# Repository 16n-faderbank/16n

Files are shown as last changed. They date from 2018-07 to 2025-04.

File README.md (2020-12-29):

# 16n

Once upon a time, Sean Hellfritsch and Brian Crabtree [made a faderbank][linespost].

**16n** is the revised version of that object: it is open-source and ready for you to make, modify, or hack.

It is currently at hardware version **1.34**, firmware version **2.1.0**.

# Repository contents

- `firmware` is the Teensy source code.
- `electronics` is schematics and gerber files for the PCB.
- `panel` is SVG/DXF files for top and bottom panels.
- `build` is build documentation.
- `browser_test` is a **legacy** test webpage to let you test your 16n. As of 16n 2.0.0, the [editor][editor] should be your point of call for debugging your 16n.

Each directory has further `README` files in for you to read.

Your first point of call for documentation, however, should be the [Github Wiki][wiki].

## 16n Details

- 16 60mm faders
- sixteen CCs over USB-midi
- sixten CCs over minijack midi (with switch to swap between standards)
- sixteen 0-5V CV output jacks, one per channel.
- I2C: monome-style I2C protocol over TRS (tip is SDA, ring is SCL), works with Monome Teletype; also, I2C MASTER mode, works with monome Ansible, ER-301, TXo, etc (may require firmware patching or modification to connected device).

Power from 5V micro-usb into Teensy on left-hand side, or from your computer.

Toggle switch allows you to swap between 'Arturia/Novation' (tip is current source) and 'Korg/Makenoise' (ring is current source) standards; board is labelled such.

## Give us a picture, then

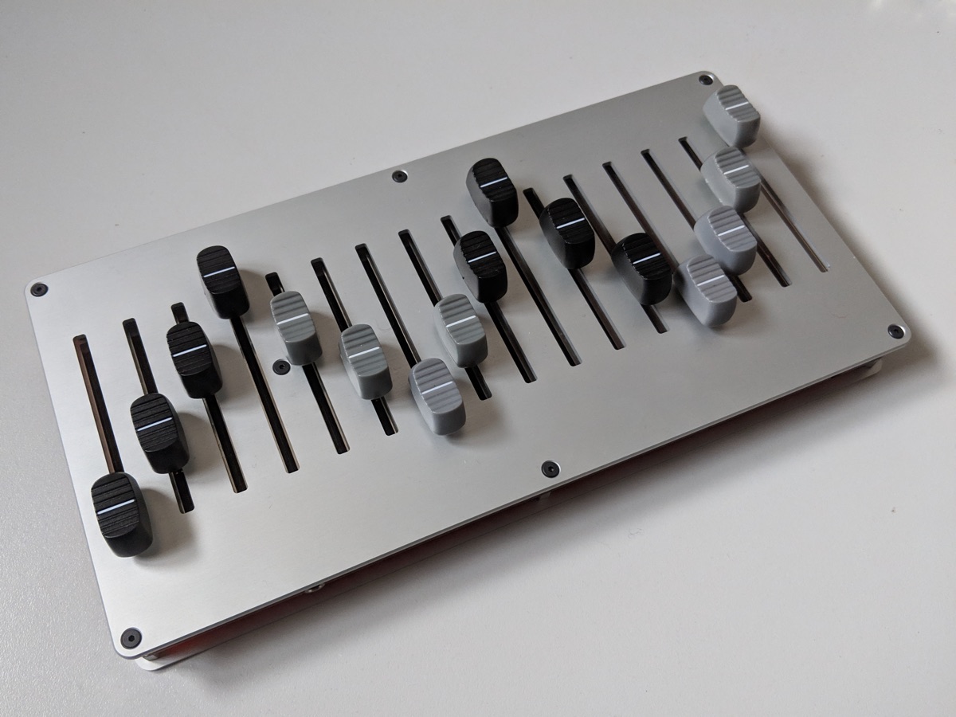
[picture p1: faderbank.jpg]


## User guide

[The user guide can be found on the Wiki](https://github.com/16n-faderbank/16n/wiki/User-Guide)

## BOM

[See more on the wiki](https://github.com/16n-faderbank/16n/wiki/BOM-(Bill-of-Materials))

## Build Guide

[See more on the wiki](https://github.com/16n-faderbank/16n/wiki/Build-guide)

## Credits

Based on original work by [Brian Crabtree][tehn] and Sean Hellfritsch.  
Minijack MIDI, I2C circuitry and CV outputs by [Tom Armitage][infovore].  
Firmware by [Brian Crabtree][tehn], [Tom Armitage][infovore], and [Brendon Cassidy][bpcmusic].

## Licensing

Panels and electronic schematics/layouts/gerber files are licensed under
[Creative Commons Attribution Share-Alike 4.0][ccbysa].

Firmware is licensed under the [MIT License][mitlicense].

[linespost]: https://llllllll.co/t/sixteen-n-faderbank/3643
[tehn]: https://github.com/tehn
[bpcmusic]: https://github.com/bpcmusic
[infovore]: https://github.com/infovore
[octobom]: https://octopart.com/bom-tool/unJxkzvR
[ccbysa]: https://creativecommons.org/licenses/by-sa/4.0/
[mitlicense]: https://opensource.org/licenses/MIT
[editor]: https://16n-faderbank.github.io/editor
[wiki]: https://github.com/16n-faderbank/16n/wiki

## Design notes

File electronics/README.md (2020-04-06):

# 16n electronics

Electronics CAD and design for the 16n faderbank. These currently use Autodesk EAGLE.

## VERSION

1.34

## Directory contents

* `16n.sch` and `16n.brd` are EAGLE 9.5.x format schematic and board layout for the project.
* `16n_schematic.pdf` is the schematic in PDF format.
* `16n_v126.brd/sch` are **old, legacy layouts that are not recommended for use**. They are kept for historical reasons.
* `bom.csv` is a CSV rendition of a BOM for the project. The parts are all highly generic - any brand of 0805 resistors will do, for instance. For more specific recommendations, the [live BOM at Octopart][octobom] has links to specific components, designed around things easily purchased from Mouser, though note that stock of one manufacturer's parts may not be guaranteed, and you might need to edit your basket to find parts in stock.
* `gerbers` contains RS-274x format Gerber files for the current version of the board. These files are named per OSHpark standards, though OSHpark is an expensive place to make a 16n - you may wish to rename before you send them to another manufacturer. Do not assume your fab house can just make these - if your fab house has specific CAM rules, you should generate your own Gerbers from EAGLE.

---

[octobom]: https://octopart.com/bom-tool/unJxkzvR

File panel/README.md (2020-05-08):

# 16n: panels

- `16n-134-top.dxf` and `16n-134-bottom.dxf` are the two panels, as exported from the CAD tools they were designed in. These should be the files you make your panel from if at all possible.
- `16n-134-top.fpd` and `16n-134-bottom.fpd` are the two panels in the correct format for Schroff's _Front Panel Designer_ software. M2.5 hardware, with countersinks.
- `16n-134-top.pdf` and `16n-134-bottom.pdf` are the two panels at life-size in PDF format, with a very, very fine stroke - suitable for laser-cutting. Be sure to check the dimensions of the files in your laser-cutting platform before you start cutting.
- `16n-134-bottom-drawing.pdf` and `16n-134-top-drawing.pdf` **are mechanical drawings** of the upper and lower panels. Note that they are drawn with countersinks for a metal panel, but do not necessarily require them. All mounting holes are M2.5, all countersinks are 5.5mm. As mechanical drawings, you should **not** use these as files to send to CNC; they are purely for visual reference.

If you need to check dimensions when you import these files into your graphics program of choice, the mechanical drawing is good reference: the panel should be 254mm across its longest dimension, edge to edge.

FPD files by [Raph Wlodarczyk](https://github.com/altitude909).

PDF files for lasercutting by Matt Kennedy.

## License

This work is licensed under the Creative Commons Attribution-ShareAlike 4.0 International License. To view a copy of this license, visit http://creativecommons.org/licenses/by-sa/4.0/ or send a letter to Creative Commons, PO Box 1866, Mountain View, CA 94042, USA.

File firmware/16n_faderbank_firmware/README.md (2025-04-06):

# 16n Firmware

16n Firmware is designed to run on a Teensy 3.2; it is also compatible with a Teensy LC, although the official BOM recommends a 3.2.

This README serves as a guide for **developing** and **compiling** your own versions of the firwmare. Since firmware v2.0.0, the recommended method for putting firmware onto a 16n is to use Teensy Loader directly. [Find out more on the wiki][load-firmware]

If you are interested in compiling your own firmware, or hacking on it, read on!

## Requirements

- Arduino + Teensyduino install (currently: [Arduino](https://www.arduino.cc/en/software) 2.3.4 with [Teensyduino](https://www.pjrc.com/teensy/td_download.html) v1.59.0)
- `ResponsiveAnalogRead` library
- `CD74HC4067` library

## Compilation

- You **must** compile this with Tools->USB type set to **MIDI**. (**Serial+MIDI** may have issues with certain devices you connect to).
- Be sure that the board speed is set to 120mhz (overclock) for maximum repsonsiveness.
- If you're having issues compiling related to MIDI libraries or code: make sure your Arduino `libraries` folder doesn't have any old versions of weird MIDI libraries in. The MIDI library should be installed by default via Teensyduino; otherwise, if you have the latest version of the 47effects MIDI library in your Libraries Manager, that'll also behave. It turns out that older versions in the legacy `libraries` folder sometimes lead to conflicts.

## Customisation and configuration

As of 16n firmware 2.0.0, you no longer should do ANY configuration through the Arduino IDE. All configuration is conducted from a web browser, using the [16n editor][editor]

When you upgrade to 2.0.0 you will LOSE ANY CONFIGURATION YOU HAVE from v1.3x. This is a one-time thing; apologies. You will not lose future configurations (and also, they are easier to back up).

The 16n will be initialised to a set of default settings (All outputs for TRS and USB set to MIDI channel 1, CCs 32-47, I2C set to follower). Once this is done, connect over USB, and go to the [editor][editor] in Google Chrome; you will be able to see the current configuration, edit the configuration, and transmit the new config to your device. You will likely need to customise the maximum fader value calibrations.

Note that if you do change any config related to I2C, you should power-cycle the 16n before it will be picked up.

Some options _do_ remain in `config.h`; they are for developers to specify options that are likely to need setting once, or adjusting during the development process:

In `config.h`

```C
#define DEBUG 1
```

will log debug messages to the serial port.

```C
#define DEV 1
```

will restrict the faderbank to its first channel. Designed for breadboard development; almost certainly not of interest.

## Memory Map

Configuration is stored in the first 86 bytes of the on-board EEPROM. It looks like this:

Addresses 0-15 are reserved for configuration flags/data.

FADERMAX and FADERMIN are 14-bit numbers; as such, they are stored in two bytes as MSB and LSB; the actual number is calculated by `(MSB << 8) + LSB`

| Address | Format  | Description |
|---|---|---|
| 0 | 0/1 | LED on when powered |
| 1 | 0/1 | LED blink on MIDI data |
| 2 | 0/1 | Rotate controller outputs via 180º |
| 3 | 0/1 | I2C Master/Follower |
| 4,5 | 0-127 | FADERMIN lsb/msb |
| 6,7 | 0-127 | FADERMAX lsb/msb |
| 8 | 0/1 | Soft MIDI thru (default 0) |
| 9-15 | | Currently unused |
| 16-31 | 0-15 | Channel for each control (USB) |
| 32-47 | 0-15 | Channel for each control (TRS) |
| 48-63 | 0-127 | CC for each control (USB) |
| 64-79 | 0-127 | CC for each control (TRS) |
| 80-82 | 0-127 | Booleans for high-res mode (USB) |
| 83-85 | 0-127 | Booleans for high-res mode (TRS) |

## LICENSING

see `LICENSE`

[load-firmware]: https://github.com/16n-faderbank/16n/wiki/Firmware:-installation-instructions
[editor]: https://16n-faderbank.github.io/editor

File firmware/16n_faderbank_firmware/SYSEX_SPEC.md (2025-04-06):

# 16n Sysex spec

The 16n interfaces with its editor via MIDI Sysex. This document describes the supported messages.

## `0x1F` - "1nFo"

Request for 16n to transmit current state via sysex. No other payload.

## `0x0F` - "c0nFig"

"Here is my current config." Only sent by 16n as an outbound message, in response to `0x1F`. Payload of 80 bytes, describing current EEPROM state.

## `0x0E` - "c0nfig Edit"

"Here is a new complete configuration for you". Payload (other than mfg header, top/tail, etc) of 80 bytes to go straight into EEPROM, according to the memory map described in `README.md`.

## `0x0D` - "c0nfig edit (Device options)"

"Here is a new set of device options for you". Payload (other than mfg header, top/tail, etc) of 16 bytes to go straight into appropriate locations of EEPROM, according to the memory map described in `README.md`.

## `0x0C` - "c0nfig edit (usb options)"

"Here is a new set of USB options for you". Payload (other than mfg header, top/tail, etc) of 34 bytes to go straight into appropriate locations of EEPROM, according to the memory map described in `README.md`.

## `0x0B` - "c0nfig edit (trs options)"

"Here is a new set of TRS options for you". Payload (other than mfg header, top/tail, etc) of 34 bytes to go straight into appropriate locations of EEPROM, according to the memory map described in `README.md`.

## `0x1A` - "1nitiAlize memory"

"Wipe the EEPROM and force factory settings". Unlikely to ever be needed. The use case is "emptying" the EEPROM of a Teensy that's previously been used for other projects, and thus has an inaccurate configuration on it.

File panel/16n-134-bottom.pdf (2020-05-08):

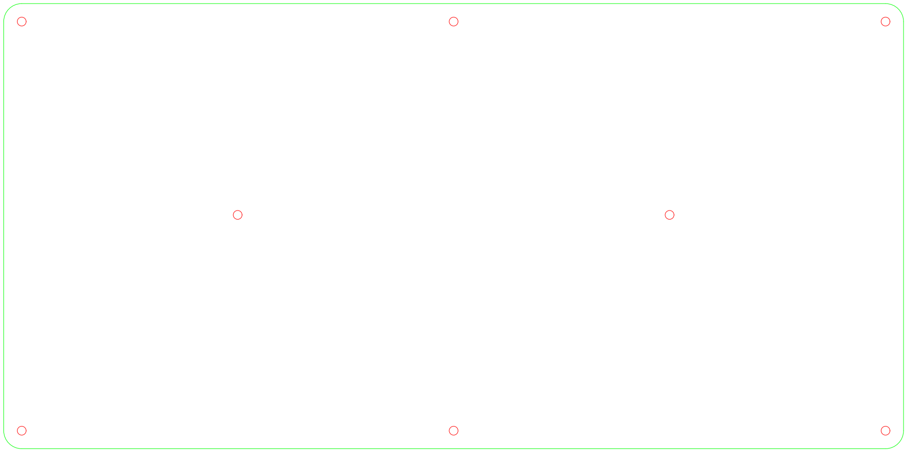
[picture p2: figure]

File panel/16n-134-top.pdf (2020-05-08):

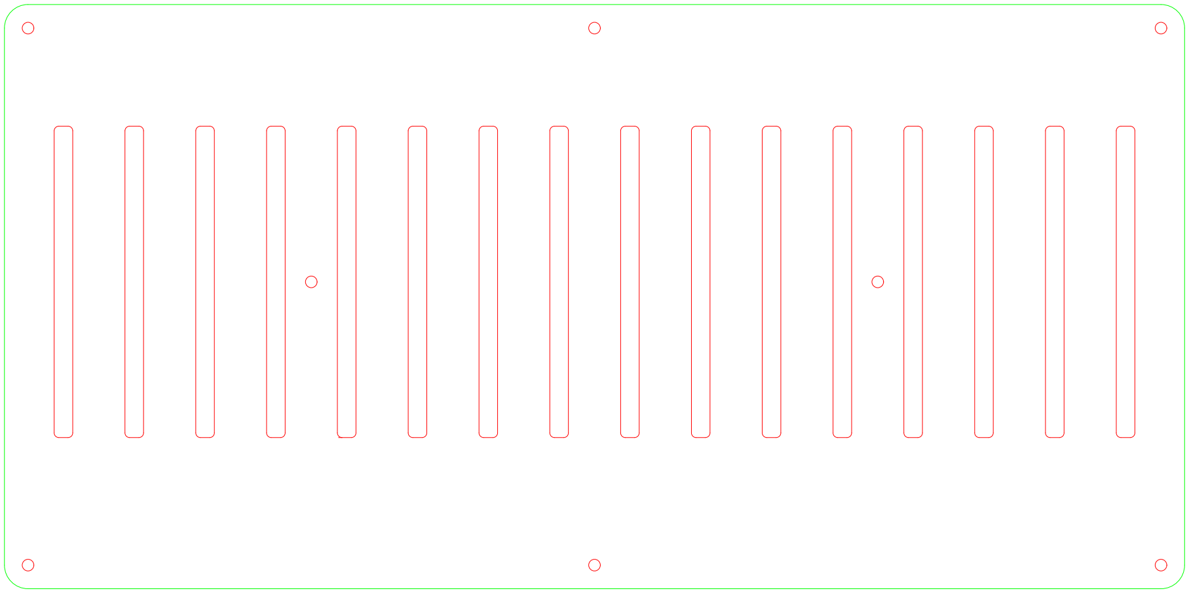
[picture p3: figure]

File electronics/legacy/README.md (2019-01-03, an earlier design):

# Legacy electronics

This directory contains older versions of the 16n circuit and PCB that are no
longer recommended for use; they are simply kept around for legacy reasons as
a few of these exist in the world. `16n.sch` and `16n.brd` in the parent
directory are the versions you should refer to.

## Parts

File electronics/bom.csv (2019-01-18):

Qty | Value | Device | Package | Parts | Description
2 |  | AUDIO-JACKPTH | AUDIO-JACK | JP1, JP2 | 3.5mm Stereo Audio Jack CUI SJ1-3523N
4 |  | DIODESOD123 | SOD-123 | D1, D2, D3, D4 | 1N4148 SOD-123 didoe
1 |  | SWITCH-DPDTEG2211 | EG2211 | S1 | DPDT Version of the COM-00597
9 | 100n | C-EUC0805 | C0805 | C1, C2, C3, C4, C5, C6, C7, C8, C9 | 0805 X7R capacitors
16 | 10K | R-EU_R0805 | R0805 | R20, R22, R24, R26, R28, R30, R32, R34, R36, R38, R40, R42, R44, R46, R48, R51 | 0805 1% Resistors
16 | 1K | R-EU_R0805 | R0805 | R1, R2, R3, R4, R5, R6, R7, R8, R9, R10, R11, R12, R13, R14, R15, R16 | 0805 1% Resistors
2 | 47 | R-EU_R0805 | R0805 | R49, R52 | 0805 1% Resistors
16 | 5.6K | R-EU_R0805 | R0805 | R19, R21, R23, R25, R27, R29, R31, R33, R35, R37, R39, R41, R43, R45, R47, R50 | 0805 1% Resistors
1 | CD74HC4067M | 744067SO24 | SOIC127P1030X265-24 | U1 | 16-channel analog MUX
2 | DNP | R-EU_R0805 | R0805 | R17, R18 | 0805 1% Resistors
8 | MCP6004_SMD | MCP6004_SMD | SO14 | U2, U3, U4, U5, U6, U7, U8, U9 | MCP6004 quad op amp
16 | PJ302M | PJ302M | PJ302M | J1, J2, J3, J4, J5, J6, J7, J8, J9, J10, J11, J12, J13, J14, J15, J16 | PJ302M horizontal / right angled mount 3.5 mm jack socket (available at Thonk) or CUI MJ-3536 (more expensive)
16 | SLIDEPOT-ALPS-60MM | SLIDEPOT-ALPS-60MM | RS6011SP6003 | U$1, U$2, U$3, U$4, U$5, U$6, U$7, U$8, U$9, U$10, U$11, U$12, U$13, U$14, U$15, U$16
1 | TEENSY_3.1-3.2_DIL | TEENSY_3.1-3.2_DIL | TEENSY_3.0-3.2&LC_DIL | U$17 | Teensy 3.1 or 3.2 in a DIL Layout.
Hardware
8 | Harwin R25-1001002 |  |  |  | 10mm F-F standoff
8 | Harwin R25-3000602 |  |  |  | 6mm M-F standoff

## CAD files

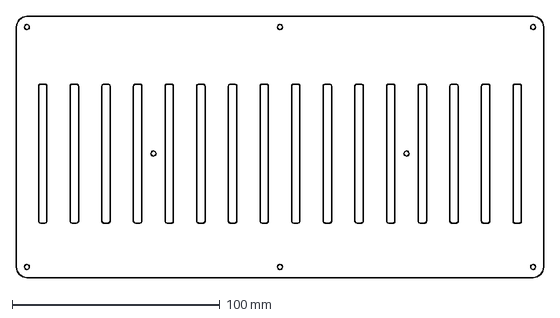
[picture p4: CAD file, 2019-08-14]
panel/16n-134-top.dxf
254.0 x 125.7 mm

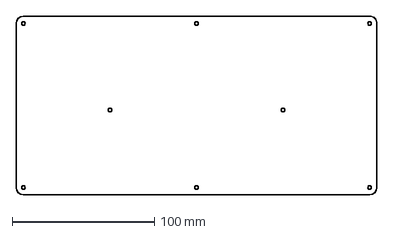
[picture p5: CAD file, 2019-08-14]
panel/16n-134-bottom.dxf
254.0 x 125.7 mm

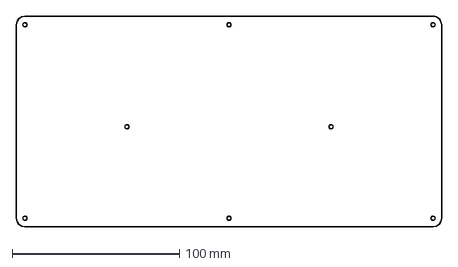
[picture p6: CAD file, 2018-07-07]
panel/16n-125-bottom.dxf
254.0 x 125.7 mm

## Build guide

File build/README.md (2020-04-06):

# 16n: v1.3x build guide

[The build guide now lives on the wiki](https://github.com/16n-faderbank/16n/wiki/Build-guide)

This directory stores the images for the build guide; do not remove.

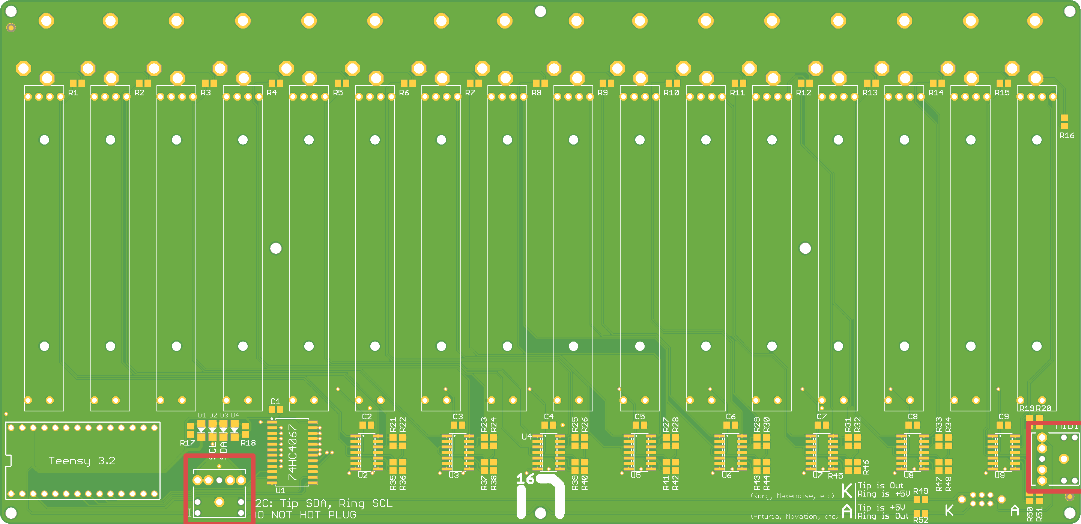
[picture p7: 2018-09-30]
build/build/16n_5_stereo.png

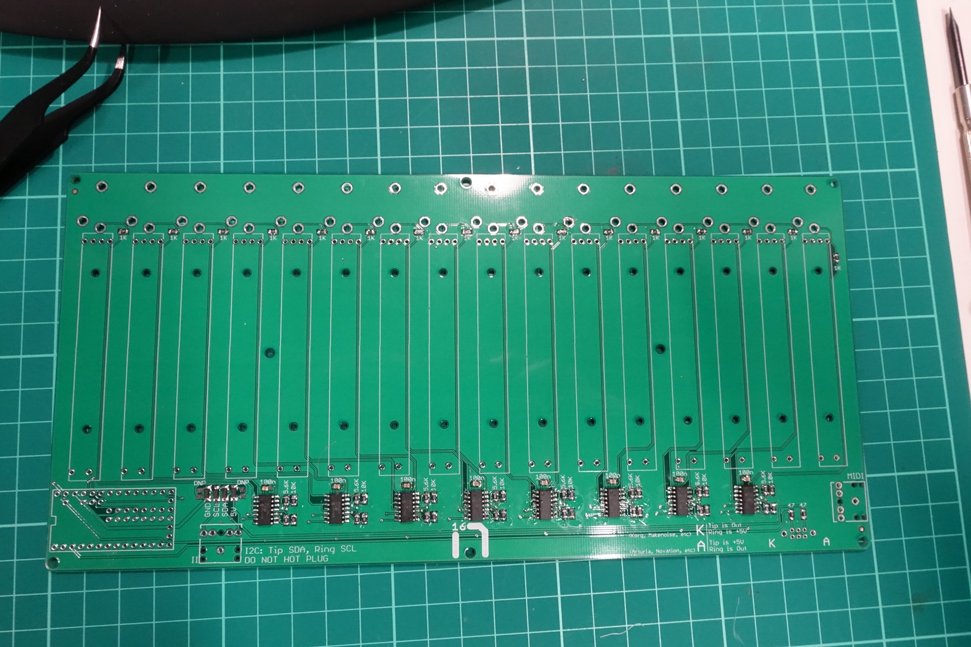
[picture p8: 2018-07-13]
build/build/DSC01717.JPG

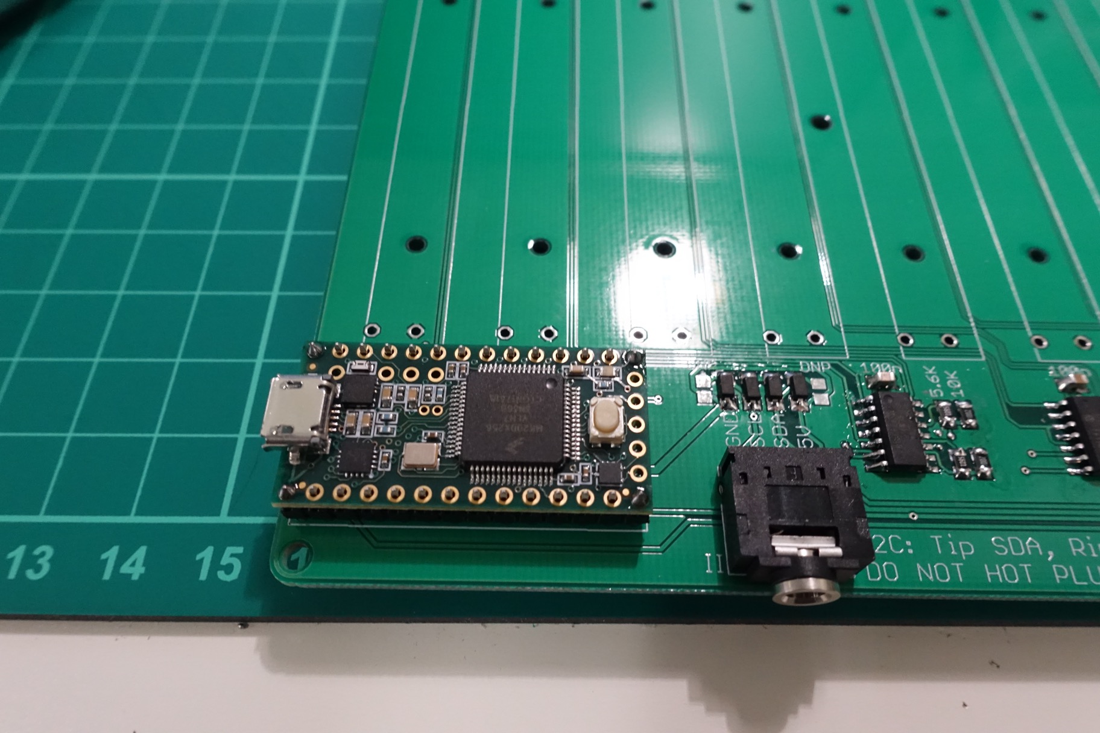
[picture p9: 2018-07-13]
build/build/DSC01723.JPG

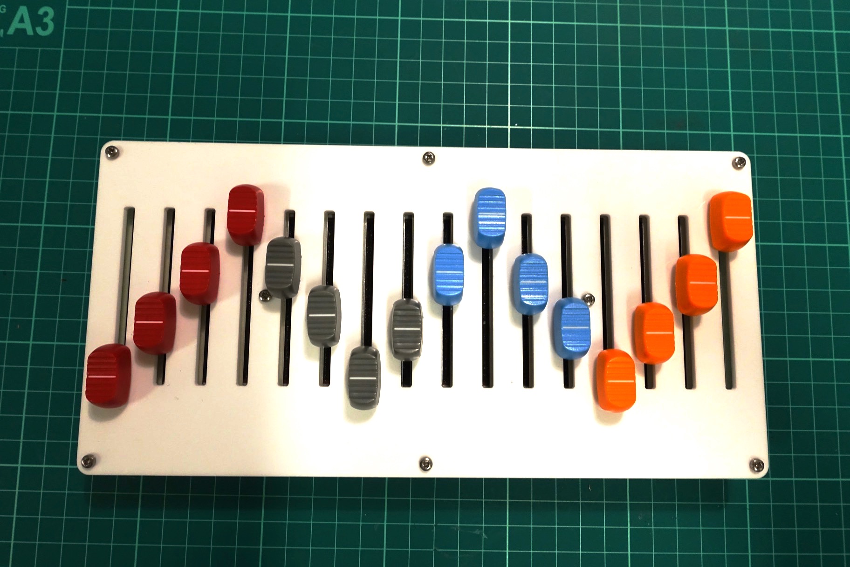
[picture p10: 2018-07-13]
build/build/16n_2.jpg

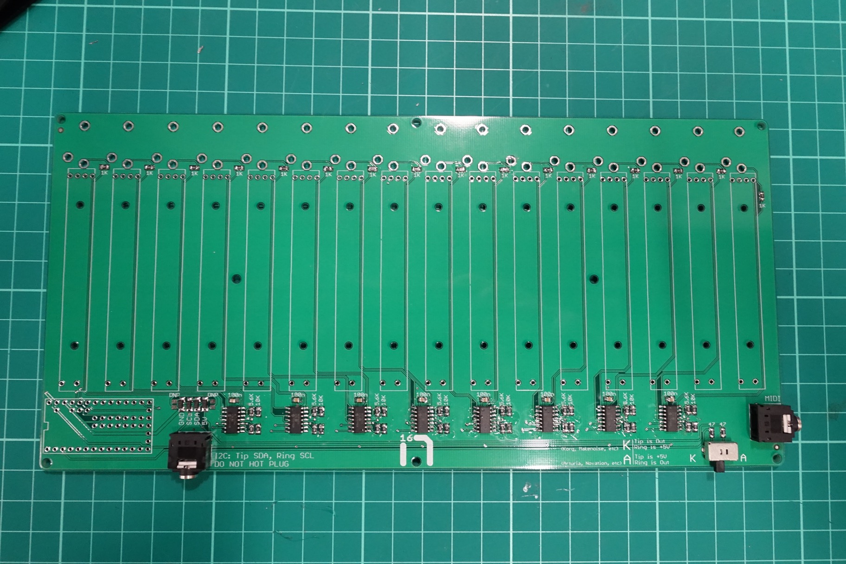
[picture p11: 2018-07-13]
build/build/DSC01721.JPG

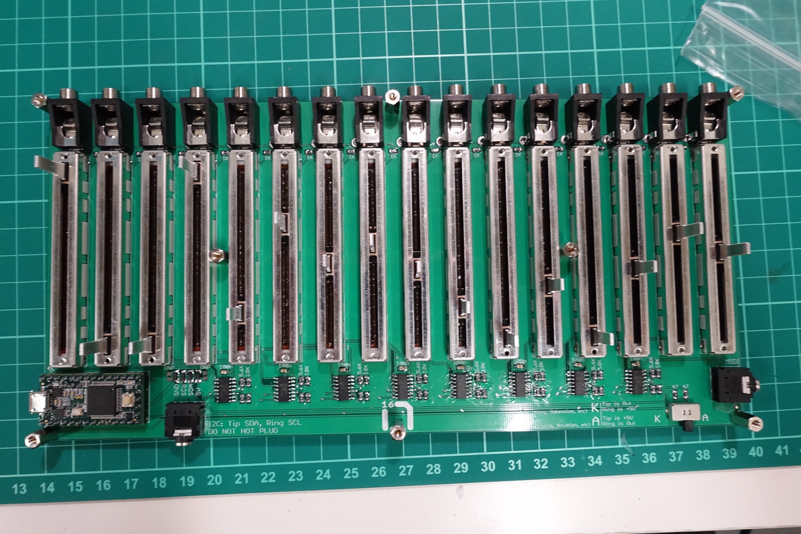
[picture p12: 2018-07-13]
build/build/DSC01729.JPG

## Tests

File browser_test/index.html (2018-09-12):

# 16n MIDI test

This test page requires a WebMIDI compatible browser; we recommend Google Chrome.

Connect your 16n via USB _or_ hardware MIDI, not both. You should see sixteen sliders that move independently when your 16n is connected. This assumes the default midi settings of CCs 32-47.

1

1

1

1

1

1

1

1

1

1

1

1

1

1

1

1

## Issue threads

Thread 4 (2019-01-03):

Add version number to Eagle files?

okyeron, 2019-01-03:
At first glance it's not obvious which eagle files are the ones to use.

Adding a version number or putting the old (1.26) version in a separate folder would help reduce confusion.

infovore, 2019-01-03:
v1.26 has been removed from the repository, because we have git history now, and no-one really should be using 1.2x.

My goal is to only have one current version. Version number is written on the rear silk of the BoaRD file - it should probably be in the SCHematic, too, though. Thoughts?

infovore, 2019-01-03:
I thought about removing v1.26  from the repository, because we have git history now, and no-one really should be using 1.2x. However, I might bung it in a folder called `legacy` and leave it at that.

My goal is to only have one current version. Version number is written on the rear silk of the BoaRD file - it should probably be in the SCHematic, too, though. Thoughts?

infovore, 2019-01-03:
(See
https://github.com/16n-faderbank/16n/tree/master/electronics/legacy)

okyeron, 2019-01-03:
Adding version to the schematic would be great.

Closed 2019-01-15.

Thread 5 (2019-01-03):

Slide Pots - 10K?

okyeron, 2019-01-03:
BOM is not specific on value for slide pots.

Mouser lists 2 versions of the RS6011SP600x - RS6011SP6003 (10KOhms) and RS6011SP6004 (20Kohms)

Datasheet says the 10K RS6011SP6003 is 1B taper (linear) so I assume this is the right one. Might be good to update the BOM with that part number?

infovore, 2019-01-03:
Octopart BOM - https://octopart.com/bom-tool/unJxkzvR - is specific and specifies 6003 (10k) parts.

However, technically, resistance doesn't matter that much as it's just being used as a voltage divider. Taper is, however, critical, and should be linear. I'll update `bom.csv` with the 6003 part though.

Closed 2019-01-03.

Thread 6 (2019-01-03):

Multiplexer missing from CSV BOM and Octopart BOM

infovore, 2019-01-03:
...and if it is, does that mean cap counts are correct too? Double check.

infovore, 2019-01-03:
Nope - turns out the _wrong_ Octopart BOM was linked up. Fixed, now.

Elberstein, 2019-01-18:
BOM.csv should be modified, it still lists CD74HC4067SM96 as multiplexer but it's the wrong package. It should be CD74HC4067M

Closed 2019-01-18.

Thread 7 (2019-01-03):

Standoff height?

okyeron, 2019-01-03:
Another discrepancy between Octopart BOM and CSV...

The CSV has 6mm M-F standoff, Octopart has 5mm

Should we assume Octopart BOM is correct?

infovore, 2019-01-03:
Well.

6mm is correct, but even though Harwin make a 6mm M-F spacer, Octopart doesn't list it.

Also: this is dependent on the length of your screws. With the counterrsunk screws, I needed a 6mm spacer to accommodate them; with panheads, the 5mm one was fine. I could go looking for alternate parts. If you're not using countersunk holes, 5mm should be fine.

This is a weird discrepancy, but I'm not sure how best to solve it.

okyeron, 2019-01-03:
So here's alternate part from mouser that's 6mm, but only 4.5 wide
https://www.mouser.com/ProductDetail/RAF-Electronic-Hardware/M2101-2545-AL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

Might be good to mention the length being an option in the docs?

okyeron, 2019-01-28:
Followup thought -  if your fader bats/arms/shafts (what are those called anyway) are too long/tall for your chosen fader caps, you could potentially get longer top spacers to raise the panel up a bit.

Useful addendum  for the build docs?

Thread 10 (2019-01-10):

Bug in panel DXFs

infovore, 2019-01-10:
Panel DXFs have 5.5mm holes at the corners, not 2.5mm.

The 5.5mm is the countersink; the drill should be 2.5mm.

This can be attributed to the DXF being extracted from fusion360 from the wrong side. Needs fixing ASAP.

infovore, 2019-01-10:
(thanks, @okyeron)

Closed 2019-01-18.

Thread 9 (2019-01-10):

Issue compiling on Windows

infovore, 2019-01-10:
As seen here:
https://llllllll.co/t/16n-is-a-bank-of-faders-release-thread-current-version-1-31/18620/118

> I’m having problems compiling the code. 1.8.8/1.45 on win10 64bit.
> `_16n_faderbank_firmware:27: error: expected constructor, destructor, or type conversion before ‘;’ token MIDI_CREATE_DEFAULT_INSTANCE();`

altitude909, 2019-01-10:
following.

infovore, 2019-01-10:
@altitude909 so here's a question - in Sketch -> Libraries -> Manage Libraries  - can you find "MIDI Library by Forty-Seven Effects" and tell me what version you have installed? You shouldn't need this - Teensyduino includes a midi library - but I'm wondering if there's a version conflict. (I have 4.3.1 of this library installed, and all compiles fine).

altitude909, 2019-01-10:
yeah, wouldn't surprise me I think im up to 7 midi libraries in there. its still up on screen, I'll check in a bit

okyeron, 2019-01-10:
I think the 47-effects lib is deprecated now (after 1.8.5). The newest teensyduino should override this.

You could try disabling the 47-effects lib and/or reinstall teensyduino

infovore, 2019-01-10:
@okyeron in thread, @altitude909 said they were on Arduino 1.8.8, Teensyduino 1.45 (ie, all latest)

okyeron, 2019-01-10:
Right - scanner_darkly had the exact same error last night on some other teensy/midi code and he fixed it by upgrading to 1.8.8 and 1.45 (on windows).

In this case my guess is the 47effects midi lib is getting loaded instead of the Teensy one?

infovore, 2019-01-10:
@okyeron no; I have the 47effects library installed; everything compiles fine. However - I was wondering if there was a conflict with _older_ versions of 47effects, which had similar issues to the one described.

altitude909, 2019-01-10:
Ok, Used: p:\Program Files (x86)\Arduino\hardware\teensy\avr\libraries\MIDI is what worked.  I had a who knows what lib that is was trying and that was breaking the build

infovore, 2019-01-10:
@altitude909 ah, yeah - so there were some changes to the core MIDI libraries a while back; older versions seemed to trigger the error you described. Old things kicking around in `.../libraries` might do that.

I'm glad you've got it working. Outputs from this: I'm going to add this clarification in the `README` before closing this issue.

Closed 2019-01-18.

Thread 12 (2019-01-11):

I2C, slave mode: wrong address

Elberstein, 2019-01-11:
I'm experiencing issues with the I2C connection. I'm testing the connection with a Teletype, when polled, it always returns 0. (See "Context" below). According to the Serial Monitor, the 16n doesn’t receive anything.

I'm not sure wether it's related to hardware or software. If it's related to the hardware, the only change I made is replacing the 1N4148W-7-F diodes by 1N4148W**Q**-7-F diodes. The specs are nearly identical but the Q-7-F have a reverse current of 50uF instead of 1uF for the 7-F.
Could this be the cause of the issue ?

**Context:**
- Teletype (old hardware, not the latest revision) Firmware number -> 25E14EE
- TT busboard.
- 16nFaderbank in slave mode
- 16n connected to the I2C bus through a TXo.
- Total cable length outside + inside the eurorack case: approx. 35cm
- Connectivity between the Teletype and the Teensy tested with a multimeter: OK (Tip: SDA, Ring: SCL, Sleeve: ground. Pins 18 and 19 on the Teensy)
- The firmware of the 16n has not been modified (except for enabling DEBUG in config.h)
- Midi (USB) and CV tested: OK.
Other I2C devices on the bus:
Backpack header 1: ER-301
Backpack header 2: Two TXo + one 16n connected in series.

(Also tested with the 16n directly connected to the TT busboard)

**Situation:**
- The ER-301 and the TXOs receive messages from the Teletype.
- **The 16n in DEBUG mode doesn't receive messages from the Teletype according to the Serial Monitor.**
- **When polled from the Teletype with `FB 1`, the result is always 0, same thing for each fader.**
- Midi (USB) and CV work fine. Midi over jack not tested. Master mode not tested as it would require placing the pull-up resistors etc, but I can do it if necessary

Thanks.

Elberstein, 2019-01-12:
New test: Faderbank directly connected to the Teletype via i2C, removed all the other devices on the bus.
Result: Apparently the 16n stopped working (judging by the USB test in browser and the LED not lit on the Teensy I had to re-upload the firmware.

Elberstein, 2019-01-13:
Thanks for your reply.

I've just made a new test connecting the 16nFaderbank directly to the Teletype without busboard this time. As I wrote yesterday, the 16n didn't like being the only device on the I2C bus with the pull-up resistors of the TT busboard. This time, the unit doesn't stop working but it always returns 0.
I have to say that all the tests have been done with two 16nFaderbank successively, I built two.

Elberstein, 2019-01-14:
In Master mode this time, the serial monitor is full of i2c messages, the 16n is connected to the ER-301
but it doesn't receive anything. I think that's normal since the faderbank seems to send i2C to an address that is not longer used by the ER-301.

```
      // ER-301
      sendi2c(0xB0, 0, 0x11, q, notShiftyTemp);
```

The new address is 0x31 I'm opening a new issue for that.

      // ER-301
      sendi2c(0x31, 0, 0x11, q, notShiftyTemp);

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

Elberstein, 2019-01-14:
OK, the issue is now fixed @infovore and @bpcmusic , it's also an issue related to the I2C address.

The address should be **0x34 and not 0x80** according to https://github.com/monome/libavr32/blob/master/src/ii.h

```
  #else
  Wire.begin(I2C_SLAVE, 0x34, I2C_PINS_18_19, I2C_PULLUP_EXT, 400000);
  Wire.onReceive(i2cWrite);
  Wire.onRequest(i2cReadRequest);
```

bpcmusic, 2019-01-15:
Looks like there was some drift since the initial versions on both sides (TT and ER-301). I've been so neck-deep in my build that I haven't kept up. Thanks for catching it!

Elberstein, 2019-01-15:
Yes, for me the changes you've made are OK @infovore

infovore, 2019-01-18:
`master` branch is now up-to-date with correct addresses.

Closed 2019-01-18.

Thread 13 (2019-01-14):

I2C, wrong address for ER-301

Elberstein, 2019-01-14:
The i2C address 0xB0 is no longer used by the ER-301.

```
      // ER-301
      sendi2c(0xB0, 0, 0x11, q, notShiftyTemp);
```

The new address should be 0x31 or 0x32 or 0x33

```
  // ER-301
  sendi2c(0x31, 0, 0x11, q, notShiftyTemp);
```

infovore, 2019-01-18:
`master` branch is now up-to-date with correct addresses.

Closed 2019-01-18.

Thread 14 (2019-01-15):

Flip device

Elberstein, 2019-01-15:
It would useful to have the possibility to flip the device, I2C connector on top, midi connector on the left.

In config.h there's an option for the fader numbers `#define REV 1` but what is the best way to also invert the values ?

I replaced   `temp = map(temp, MINFADER, MAXFADER, 0, 16383);`
with   ` temp = map(temp, MINFADER, MAXFADER, 16383, 0);`

It works but the lowest MIDI value is always 2 or 3. How can I adjust that please ?

infovore, 2019-01-15:
I'll have a think. I think the nice feature would be to have a single `define` flag like the L-R reversing, called `FLIP`, that would just make this happen.

infovore, 2019-01-15:
In the meantime - have a go at reducing `MINFADER`, which is line 34 in `config.h` - basically, might be worth fettling the sensitivity of the analog read. I'll look into this further in coming days. For now, I'm just kicking off a branch to work on this.

Elberstein, 2019-01-15:
Unfortunately, the hack `temp = map(temp, MINFADER, MAXFADER, 16383, 0);` doesn't seem to work with I2C, and reducing the value of MINFADER does't seem to have any effect

infovore, 2019-01-15:
OK, duly noted. Pretty sure I can come up with a solution for this - but not before Friday this week!

infovore, 2019-01-18:
OK, @Elberstein . I've taken a quick pass at this in a branch and got a PR open for it - https://github.com/16n-faderbank/16n/pull/17 . If you're comfortable downloading that branch and flashing that firmware, can you let me know how you get on? I've tested it on my 16n, which, over USB MIDI, behaves correctly when `REV` and `FLIP` config settings are set to 1. We can move discussion over to the PR if you'd like.

Elberstein, 2019-01-18:
I'm not really familiar with Github, I have to learn but it's not a problem.
Thanks for adding this feature. I've just tested it with the Teletype. It works but the minimum value is around 350 even if MINFADER is set to 0

infovore, 2019-01-18:
OK, I think I have it working now. If you get the firmware in this branch - https://github.com/16n-faderbank/16n/tree/flip_feature - and enable `FLIP` and `REV`, my debug log seems to send correct I2C out when the thing is upside down.

Elberstein, 2019-01-18:
Yes it works but I have to increase the MINFADER value up to 200

infovore, 2019-01-20:
Merged to master.

Closed 2019-01-20.

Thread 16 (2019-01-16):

Multiple faderbanks on the same I2C bus

Elberstein, 2019-01-16:
Is it technically possible to have multiple faderbanks on the same I2C bus ? I'm wondering if it has already been tested.

Out of curiosity I tried to add an offset here but of course, it doesn't work :-) And I realize that teletype/src/ops/fader.c would probably need a modification, too.

```
    // map and update the value
    noInterrupts();
    currentValue[i] = temp;
    interrupts();
```

Thanks.

infovore, 2019-01-18:
I don't think so. Disclaimer: I am not the I2C expert.

Basically, in non-master mode - the default for Teletype - each device needs an address, and Teletype only knows one 16n address (for the device `fader`); adding more faderbanks would need more addresses over in Teletype land.

It _might_ be more possible in MASTER mode, because it's multiple devices sending to endpoints, but even then, code modification would be required - setting custom addresses, possibly changing the fader data sent over I2C.

So: for now, I'm paging Brendon (when he has time), but my gut says not without significant work. I also think that work would be largely user-unfriendly for an edge case.

Elberstein, 2019-01-18:
Thanks for your reply.
Yes, I see two options for the Slave mode:

A: Probably the best solution. More addresses in Teletype like you're suggesting (i.e: 0x35 etc.) and the user can change this line to reflect the address of the device   `Wire.begin(I2C_MASTER, **0x35**, I2C_PINS_18_19, I2C_PULLUP_EXT, 400000); ` or a variable in config.h (?)

B: Increasing the number of ports in Teletype (fader) and adding an offset (+ 16, +32) to the port number, that seems more complicated.

In both cases, it requires a modification of the teletype code.

Multiple Masters on the same bus: I'm not sure what will happen but I need to try that, if one faderbank can talk to the Teletype and another to the ER-301 while keeping the ER-301 connected to Teletype, that would be great.

bpcmusic, 2019-01-19:
You could have a one in normal mode and one in master mode, i think (but haven't tried it). Things get complicated with the Teletype as it isn't a fan of multiple masters at the moment. So, until that gets resolved (and scanner_darkly has a lead on that), you wouldn't have a stable multi-master configuration.

If you want to have two that you READ from, we could enhance the firmware to support another set of addresses. It would work the same way that it was coded for the TXi. Basically, the Teletype knows that each device has N inputs and for queries outside of that index, it advances in the address space one and normalizes to the appropriate input on the device. For example, TI.PRM 5 = TI address #2; knob 1.

That all means adding more sequential addresses for the 16n and updating the TT code to know about multiple 16n. At the bare minimum, the 16n firmware would need to be updated and compiled with the new address(es). It also could be modified to increment the ports that it sends to in Master mode - which would make sense.

I decided not to do all this (even though I have the code from my TXi implementation) to keep things simple and easy to modify by others. Given the Teletype's script limitations, I've found creatively using all 16 sliders to be a challenge in and of itself. :)

infovore, 2019-01-20:
@Elberstein I think this is effectively resolved? Before I close it, I think the best thing to do is convert @bpcmusic's response into some documentation. Is that OK?

Elberstein, 2019-01-20:
Yes, the work is on the Teletype side, I think we can close this issue :-)

Closed 2019-01-20.

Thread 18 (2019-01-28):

Put i2c address in config.h

okyeron, 2019-01-28:
Just in case people want to change the i2c address, it would be way easier to have that as a DEFINE in config.h instead of hardcoded in `Wire.begin()`

infovore, 2019-01-28:
Good idea. PR/branch open here for your review: https://github.com/16n-faderbank/16n/pull/20

infovore, 2019-02-01:
Fixed!

Closed 2019-02-01.

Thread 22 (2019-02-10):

Has anyone replaced ALP sliders with Bournes LED sliders?

JKMinWA, 2019-02-10:
I'd like to build this, but can't find the ALPS faders listed in the BOM.  I'd prefer to have faders with LEDs and found Bournes faders with dimensions and mechanical and electrical characteristics comparable to the ALPS that have LEDs in the lever.  Has anyone made this substitution?  Is this a straightforward replacement, or is there some other factors I need to consider or adjustments I need to make?

Thanks in advance for any advice.

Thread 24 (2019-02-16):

Panel thickness?

cschol, 2019-02-16:
Using the Alps faders from the BOM, what is the optimal panel **thickness**, especially for the top panel?

okyeron, 2019-02-20:
Depends on your fader caps maybe?

The mixer style caps I have are meant to be more flush to the panel so I found using a 13mm spacer with a 1/8in panel works well.

infovore, 2019-02-20:
In the images you've seen of the aluminium panel, I've been using 2mm aluminium. I've also successfully made one with 3mm plastic. The plastic one uses 10mm spacers up top, 5mm below; the metal one uses 6mm spacers below owing to countersunk holes requiring a bit more depth for the screws. Does that help?

cschol, 2019-02-20:
Yes. Thanks! I have ordered a 3mm plastic panels. That should work.

Closed 2019-02-21.

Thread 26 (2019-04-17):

faders not going to full value on midi

altitude909, 2019-04-17:
Someone brought up that their device is sending CC values over 124 and I checked several devices here and some do some do some dont.  Its persistent over all the faders for given device.  5V is good in all cases..

jamiemccusker, 2019-05-06:
Same issue here in the one I’ve built . Midi goes from 0-124. Any ideas?

andrewh, 2019-05-06:
I've also had issues finding the right values for `MINFADER` and `MAXFADER` in `config.h`. Would be good to know what others are using to get stable 0-127 over usb-midi.

I've played around and had `MINFADER` at 294 which went to MIDI 0, and `MAXFADER` at 8135 which went to MIDI 127, but the Arduino app's serial debug monitor picked up values coming in from other faders (all set to 0), so maybe there is a sensitivity issue for certain values in `config.h`?

pppier, 2019-05-25:
I also read 26 to 100 picking midi from TRS; and 0 to 124 using MIDI over USB...
I hope there's a way to have 0-127 on both...
is there a  way to check if I2C is working even if not owning a monome (like the midi html test page...) ?

jonnybutler, 2019-11-15:
I’ve noticed this happening depending how it’s powered. I had it plugged into my computer via a hub and that was enough to lesson the voltage it was operating with, which I think in turn affected the max midi value.

altitude909, 2019-11-15:
That's how it works.  The reference voltage for the faders is directly taken from the USB supply voltage and those can vary widely.  What ive been doing is lowering the range of the ADC to 8000, this gives a bit of a dead spot at the top some times but it will always go to 100%

andrewh, 2019-11-19:
So maybe the fix here is just some documentation?

scaleandthreshold, 2021-08-16:
All my faders go from 0-125, I confirmed this in the MIDI Test Page.
I then installed the latest firmware meaning I can't use the MIDI Test, but can now use the Configuration Tool.
Same problem.

I'm not using CV just MIDI over USB.

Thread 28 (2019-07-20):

Error when compiling windows 7

jondent808, 2019-07-20:
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
Hello, I have  an error when compiling:
stray '\302' in program

infovore, 2019-08-26:
That's not the real 16n code. That's an HTML page. What did you click to download that, or to clone the repository?

If you want to compile from scratch, you should either clone the whole repository via git, or you can download a release from the [releases page](https://github.com/16n-faderbank/16n/releases) - where you can see both "Source code" compressed folders (which represent the entire state of the repo at that release, a bit like cloning the specific tag) or precompiled binaries and CAD files.

The thing you've shown above is never ever going to compile, because it's not arduino code; it looks like the sourcecode to a github page, which you may have downloaded in error.

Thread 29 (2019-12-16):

Motorised Sliders - suggestion

deskofcraig, 2019-12-16:
Is it possible to use motorised sliders that can snap to preset values from the host to give a true value when using the 16n?

infovore, 2020-01-20:
Right now, it is not "possible" in the sense that you can't just put motorised faders in place of the current faders, write some code, and have it work.

Yes, it would be cool.

This idea has been suggested in multiple locations on multiple occasions, and it's worth going over the changes necessary to doing this, if only to archive them:

* the firmware needs to parse MIDI input to take the values the host is sending it.
* the electronics now need to be added to, to send values to the motors - is this analog? is this stepper instructions? regardless, there are extra constraints, and more pins on the Teensy/MCU to be used (and possibly more support componentry to be added. Motor drivers, possibly?)
* the fader parts need replacing with motorised hardware. these are physically larger than the current parts, primarily _depthwise_.
* ...which means that the board will need re-designing, and it's going to be a physically bigger object...
* ...which will mean redesigning the panels/case.

Motorised alps 60mm faders are around... 7x the cost of the standard faders. You'd spend €400 on faders alone to build this.

As you can see, it's not easy, or cost effective. Personally, I'm not very interested in working on this project.

However: 16n is opensource, and you have all the starting points to adjust the design.

sapyatkuen, 2020-10-29:
You can find in Thomann a 5 Behringer motor fader kit for 89€ and there are plenty of other ones in AliExpress.

In my case I´d be very interested in a 16n with motorised faders to use with Ableton, or at least a motorized 8n (with a button that sends CC61) to connect to the Octatrack.

infovore, 2020-10-29:
@sapyatkuen fine, so you've found some cheaper faders, and a 16n made with Behringer faders would cost you 287 euro, not 400. however, that behringer part is.. an I don't know what, so you need to go find a footprint for it, or make one; it looks alps-ish, fortunately. If you look at the form factor, and where the motor goes, you now have to leave holes in the PCB, which will make it much larger in terms of both the Y axis of the pcb and the Z axis of the enclosure. And then you have to wire in the stepper motors, and add stepper motor drivers, and and and... all my comments around the electronics still stand, and we've only saved 100 euro.

(In general, I like projects where parts are _sourecable_, and relying on a random thing from AliExpress is no guarantee it will be available in future. So that's not really a solution.)

I'm closing this thread, because "motorised faderbank based on the 16n project" is a new project, not a neat feature we can add, and not one I have any interest in adding.

As ever, the 16n mantra applies: _that's a really interesting idea, but Tom's not interested in doing it. The whole project is open source, and you can get all the tools to make these changes. Why not try?_

Closed 2020-10-29.

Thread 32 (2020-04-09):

16nLC boards should identify themselves via a different devicetype.

infovore, 2020-04-09:
The DEVICE_ID inside `config.h` should be dynamically set dependent on Teensy LC or 3.2.

infovore, 2020-04-09:
Fixed via 630bbd522a7677f6885ec799937e4f7a8df39156.

Closed 2020-04-09.

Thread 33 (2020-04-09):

Add inbound sysex message for USB options.

infovore, 2020-04-09:
32 byte inbound message for USB-specific options: 16 bytes of channels, 16 bytes of CCs.

Note that this data is not contiguous inside EEPROM, so will need two write passes on the device firmware.

infovore, 2020-04-09:
Resolved in bd058c79f209219ed7a57085bd62af94bf46ee0b.

altitude909, 2020-04-09:
The 60 Byte thing is a quirk of the teensy, you can change it in \avr\cores\teensy3 usbmidi.h to 90

infovore, 2020-04-09:
Yeah, I found that after some late-night googling. I decided, rather than altering core code, to work around it.

So the current fix is to identify the LC boards (and have them identify themselves to the editor), and make sure that rather than sending them 90 bytes of sysex, we send them 3 lumps of < 60. (In this case, 16, 32, and 32). It wasn't so challenging to sort that out, and makes it more reliable to compile up the firmware from source. It also means we don't have to change that again in the future. The bigger limitation on the LCs is their limited EEPROM size - we're underneath the 128byte limit for sure, but it's a thing to be wary of in the future.

Just testing my supposedly fixed firmware with some US folks who are helping me, and we should have a fully compatible thing out over the weekend. That's the plan, anyhow.

infovore, 2020-04-09:
@altitude909 all changes on the firmware side are in this (in progress) PR: https://github.com/16n-faderbank/16n/pull/36/files

Closed 2020-04-09.

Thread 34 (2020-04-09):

Add inbound sysex message for TRS options.

infovore, 2020-04-09:
32 byte inbound message for TRS-specific options: 16 bytes of channels, 16 bytes of CCs.

Note that this data is not contiguous inside EEPROM, so will need two write passes on the device firmware.

infovore, 2020-04-09:
Resolved in bd058c79f209219ed7a57085bd62af94bf46ee0b

Closed 2020-04-09.

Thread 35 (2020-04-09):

Add inbound sysex message for device options.

infovore, 2020-04-09:
16 byte inbound message for device options. Good first issues, as those sixteen bytes are contiguous.

infovore, 2020-04-09:
Resolved in bd058c79f209219ed7a57085bd62af94bf46ee0b.

Closed 2020-04-09.

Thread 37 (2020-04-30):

Slider resistance is absent in BOM

vafu, 2020-04-30:
seems that https://github.com/16n-faderbank/16n/blob/master/electronics/bom.csv doesn't say anything about resistance of sliders needed. also, octopart link gives 404.
what is correct slider resistance value ?

infovore, 2020-05-12:
The part reference for the slider - `RS6011SP6003` is specifically for a 10k linear part. You can also get 20k linear, they'd work fine. The resistance doesn't really matter, but it's important that they are linear, rather than log, taper.

Octopart BOM shouldn't be 404ing. I'll look into that.

altitude909, 2020-05-12:
Just FYI, ALPS doesnt make a linear pot in anything but 10KB.  AFAIK, Alps is the only stocked part in that configuration (single B10K in a dual footprint) out in the wild so it has to be that exact part

infovore, 2020-05-12:
oops, thank you for clarification, @altitude909!

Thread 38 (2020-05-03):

Only send messages when values change

trentgill, 2020-05-03:
At the moment MIDI and I2C messages are sent as fast as the main loop can.

If a tiny amount of hysteresis was added to the smoothed analog value, messages could be only sent when the sliders are moved. This could make 16n coexist on an i2c bus (as a leader) with multiple leader devices.

Is there any reason why this would be a bad idea? If not, I'm happy to submit a PR to do this.

infovore, 2020-05-28:
I was about to write "hang on, I thought we throttled this' (there's been some rewrites of the analog-read code over time). We appear to be using a mixture of `ResponsiveAnalogRead` and manual "has something changed"; really, RAR provides a lot of that - including IIRC a little hysteresis for us.

So: possibly worth doing a tidyup to use the code we've got better.

But I genuinely thought we _were_ only sending messages when sliders changed? Are we not? Or are i2c and midi behaving differently? Sounds like something fishy is going on here.

trentgill, 2020-05-28:
Full disclosure I don't have a 16n to test with! I had just made this assumption from reading the code and not being familiar with `ResponsiveAnalogRead`'s semantics. Apologies for opening this needlessly! I've just been trying to deal with the context of allowing multiple-leader devices on the same i2c bus (specifically re: Crow).

Closing this issue & thank you for the explanation!

infovore, 2020-05-30:
TBH it's still all a bit ugly, and could probably be tidied - I hate how messy some of the forking has got. So it's still worth a look.

And - I'm dealing with the mirror problem: I have a 16n but no i2c devices, and so I'm largely in the dark on i2c fixes.

Closed 2020-05-28.

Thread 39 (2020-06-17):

Teensy troubles

ian-c121, 2020-06-17:
hi all,
apologies if this is a stupid question, but i'm having issues with my teensy.
i'm a kit builder, so the build was nice and straightforward. now "all" i've got to do is shove a bit of code into it.
i've downloaded everything, opened the loader, done the verify (tick) stage, but now i'm stuck.
how do i get the v201 hex file into my teensy??

any help would be much appreciated.

cheers,
ian c.

infovore, 2020-06-23:
When you say, "opened the loader", do you mean "Arduino" or the actual Teensy Loader software?

[The instructions on the wiki are your best bet](https://github.com/16n-faderbank/16n/wiki/Firmware:-installation-instructions); you should download a standalone Teensy Loader, and from that little window you can 'open'/load the .hex file. You should then be able to flash it to the Teensy that's connected. If you're having difficulty with the connection, check your micro-usb cable is a real data cable, not just a charging cable.

You don't need to compile the sourcecode yourself in Arduino.

Sorry if that's just repeating what the wiki says.

ian-c121, 2020-06-23:
hi infovore,

thanks for the message.

i'm referring to the teensyduino. i'm sure i'm ok up to that point, but then the fun starts.
good thought about the cable, though. i'd had that thought myself, as everything else looks ok. so i'll check that and try again.

thanks again,
ian c.

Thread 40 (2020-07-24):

v201 non-working + weird debug message

modularev, 2020-07-24:
Hi there!

Not sure what the issue could be, but my 16n worked flawlessly with the v134 firmware but is now acting up when installing v201.

I tried installing the hex and compiling it myself. Serial Monitor tells me:

`Got an 1nFo request`
`Sending this data`
`7D 00 00 0F 02 02 00 01 01 4C 41 43 02 00 00 00 74 00 D9 CB D4 13 5E 2D E7 46 75 60 F8 79 80 93 09 AD 91 C6 19 E0 A1 F9 7F 7F 9A 13 29 2D B2 46 3A 60 CC 79 52 93 DF AC 65 C6 EB DF 76 F9 7F 7F 84 13 09 2D 94 46 18 60 A6 79 2B 93 B1 AC 3D C6 BF DF 43 F9 7F 7F D8 13 `
`Ooh, sysex`
`F0 7D 00 00 1F F7`

Thanks a lot and all the best!

infovore, 2020-07-27:
So, if you're looking at serial monitor, and have debug messages enabled, and are watching serial monitor whilst you're using the editor tool, that looks OK in the sense that it's the correct debug code.

However, the data being sent looks like garbage:

`7D 00 00` is our manufacturer message.
`0F` is the indicator we're sending a `c0nFig` message
`02` is our device-type ("16n faderbank")
`02 00 01` is our firmware version (2.0.1)

and then the rest is an eeprom dump, and many of those bytes are just not right.

So, question: did you use this Teensy for anything else before this project? I ask because I think this is related to #41

modularev, 2020-07-27:
I‘m the one from the lines forum so I guess this issue can be closed :)

Closed 2020-07-27.

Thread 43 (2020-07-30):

2.5 mm screws missing on BOM?

montoyamoraga, 2020-07-30:
hi!

are the 2.5 mm screws included on the BOM? i couldn't find them :)

infovore, 2020-08-04:
They are not, partly because the screws you require vary dependent on the panels you have chosen. For instance, I have a countersunk panel, so use countersunk screws, but if you don't have countersinks, those won't work, and you'll need flathead screws.

The BOM as supplied is for the electronics assembly, basically; panel and case are left off it.

montoyamoraga, 2020-08-04:
oh that makes so much sense, thank you @infovore :)
do you want me to add a paragraph to the Wiki or do a PR mentioning this, happy to!

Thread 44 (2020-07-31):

Inconsistent midi experience

doodlewhale, 2020-07-31:
I am unable to get the 16n to communicate with Ableton live. I also cannot find the device in the editor tool https://16n-faderbank.github.io/editor/ BUT this test page confirms midi is being received https://modularden.co/16n-test/ I am confused. Is the editor broken?

doodlewhale, 2020-07-31:
OK, so a reflash of the firmware seems to have brought it back to life but fader 1 is now not working! 2 thru 16 are fine.

doodlewhale, 2020-08-03:
Ahhhd, it's back to working again after another re-flash and a clean up of midi in the registry. :/

Closed 2020-10-17.

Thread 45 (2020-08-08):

16N not recognized on Mac

matpap, 2020-08-08:
I got 16N via USB to Mac. The Teensy has light that comes on, but nothing is being recognized on computer either using the configurator in Chrome https://16n-faderbank.github.io/editor/. Any troubleshooting recommendations?

matpap, 2020-08-08:
swapped out for another cable and works like a charm now

infovore, 2020-12-22:
👍

Closed 2020-12-22.

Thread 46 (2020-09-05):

Fader 1 controlling all values

apossibleworld, 2020-09-05:
Hello -- I recently purchased a used 16n on Reverb.  I just updated to the latest firmware, all good.  In the web editor, fader 1 is controlling all of the other fader values, and the other faders do nothing.  So in the editor display, when I push up the first fader, I see all 16 move up to 127.

Any suggestions or help?  I don't know who assembled this unit, unfortunately.  I am also totally not a programmer, just a musician trying to do cool things with this great system.

thank you!

apossibleworld, 2020-09-11:
Can anybody help me troubleshoot this?  The two previous owners don't know who built it, but say it used to work fine.  Are there older versions of the hardware that don't work with firmware 2.0.1?

infovore, 2020-12-22:
There _is_ an older version of the hardware that needs a special compilation flag set for it. The obvious way to identify it is from the screws that hold the panel to the board: if they are all at the 'edge' of the board - two on each side towards the CV jacks, and one at the bottom corners - that's a 1.2X board. If the screws are laid out in two "X"s, then you've got a 1.3x board.

If it's a 1.2X board, reply here, and I can compile you a 2.0X firmware that'll work for you.

infovore, 2020-12-30:
(This was related to it being a 1.2x board! So I'm closing the issue.)

Closed 2020-12-30.

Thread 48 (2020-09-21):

Solder troubleshooting

mlinton, 2020-09-21:
So I have some pretty sloppy soldering on my board (my first SMD build) and I'm now getting some strange behaviour.

Most of the pots (1-4)seem to work in a range from 0-109
Pot 5 isn't working at all
Pot 6 goes from 0-127 then raises all the other values by 24!
Pot 8 goes from 0-15
Pot 11 and 12 don't work at all.

Should I be suspecting my 805 resister soldering?  Is there a technique that works best for these?

mlinton, 2020-09-24:
ok flowed a bunch of the solder and got all but encoders 8 and 9 working.

Still looking for a way to trace encoder 8 and 9 to find out what's wrong.  Thanks!

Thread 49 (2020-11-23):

I want to design the perfect mate for the 16n

sapyatkuen, 2020-11-23:
Hi,

I´m trying to design a mate for the 16n: the **64n**, _3 potentiometers and 1 encoder_ to match each one of the fader.

How can I figure out what components it will need? Will it work with the Teensy 3.2? I suppose I´d need a small multiplexer for each pot like the 16n has one for each fader but, will the big multiplexer be enough to handle them?

The only outputs it will have are USB and jack for MIDI, no I2C required.

Thanks!

infovore, 2020-12-22:
> How can I figure out what components it will need?

I'm guessing what you're asking really is: how do I design the electronic circuit? There isn't really a shortcut here. It just takes time and starting with smaller projects. What you describe isn't exactly a bad project to begin with, although I'd start with a single channel of it to learn some ins/outs.

Potentiometers fed with 3.3V can go straight to a Teensy analog in. Encoders require two input pins per encoder on the MCU, and you'll need a pair of pull-up resistors for every encoder. Once you start adding multiplexers, you'll want power filtering capacitors for multiplexer chips. If you're using a jack for MIDI, you'll also need a couple of resistors there - you can find out the values relatively easily online.

The [schematic](https://github.com/16n-faderbank/16n/blob/master/electronics/16n_schematic.pdf) will give you some clues.

But I can't answer the question further because it's _the work_ of designing such a thing.

> Will it work with the Teensy 3.2?

You could absolutely built that around a Teensy 3.2

>I suppose I´d need a small multiplexer for each pot like the 16n has one for each fader but, will the big multiplexer be enough to handle them?

There is _one_ multiplexer on the 16n. It takes sixteen analog inputs and routes them to a single pin. To do that, it uses four 'switching' pins, which are set high/low to define which of the sixteen inputs to read from, along with a fifth pin to 'enable' the multiplexer. On 16n, we just leave that fifth pin high all the time.

Multiplexers are easily found in 8 or 16 channel versions. They are quite easy to daisy-chain the pin-select channels on; that means you need four Teensy pins to choose channels 1-16, and then one Teensy pin for every multiplexer.

"Will the big multiplexer be enough to handle them" == I guess you're asking about channel count. No, it won't. Get more, daisy-chain them. The [datasheet for a CD74HC4067](https://www.ti.com/lit/ds/symlink/cd74hc4067.pdf) will give you some hints as to how.

It's a nice idea for a controller. I'd honestly start by trying to make one channel work on a Teensy on your bench with a breadboard and jumper wires.

I'm closing this issue, because it's not an "issue" with 16n.

Closed 2020-12-22.

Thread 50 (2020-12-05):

[Firmware Suggestion] - Midi clock from USB to Midi jack.

AtoVproject, 2020-12-05:
Hi,

I was thinking that it would be a great addition to the firmware to be able to have the Midi clock transmitted to the MIDI jack when the 16n is connected to a DAW.

This would allow to control parameters in the DAW and a Midi device while maintaining synchronization without the need for extra cables and Midi Thru and all that.

Let me know if that's something you would be willing to implement.

Cheers

AtoVproject, 2020-12-18:
Hi,

Just for info, I started implementing this already.
I'm also working on having a midi tru functions as well.

Closed 2020-12-22.

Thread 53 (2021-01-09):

negative 5v

nemoy, 2021-01-09:
this isn't really an Issue, rather an idea.
many Eurorack Modules use + / - 5v control voltages.
Is there a possibility to send negative 5v out?

infovore, 2021-01-10:
Not without changing the circuitry:

* the 5V source coming in is from the USB +5V line
* this is what the faders divide down, entirely in the analog domain, to output from the jacks. If you wanted them to output -5V, you'd have to find a way of getting a -5V reference into the fader input...
* ...but that fader output is _also_ sent through the opamps to be divided down to 3.3V levels to go into the Teensy. We can't feed negative voltages into those ADCs.

There are 16n variants that support wider voltage ranges - 0-5, 0-10V, and -5V-5V - I believe the Tesseract Modular "Sweet 16n" does. Michigan Synthworks XVI, which is not compatible with 16n firmware, but certainly inspired by it, also has a more flexible range of voltages.

Of course, if you wanted to modify the electronics to do so, you'd be welcome to work on your own derivative or related projects. To do it whilst still only using USB +5V in requires some boost conversion, I'd imagine.

Closed 2021-01-10.

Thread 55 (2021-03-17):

Can’t connect my fader bank to the editor, need help !!!

Photozik, 2021-03-17:
Hi,
I tried to connect my faderbank to the editor via Chrome, but it seems it can’t be recognized.
The editor sent this message : "It looks like a 16n is trying to connect, but may have a corrupt memory », and this : "Click to reset your 16n's EEPROM to factory defaults ». I clicked but nothing happens.
Is there a way to resolve this issue ?
Thank you very much.

infovore, 2021-03-23:
Sure, let's go over some diagnostics:

* what version firmware is your 16n running?
* was the Teensy on it used for anything else beforehand?
* did you assemble the 16n yourself?

Photozik, 2021-03-23:
Thanks Tom.
I didn't assemble the 16n myself. It's a second hand. It was originally made by Big T Music in UK but I bought it in US.
So I don't know if the Teensy was used before but I guess no, as it is a "factory" like unit.
The version mentioned on the advertisement is 2.0.0.

infovore, 2021-03-23:
Ah, OK. You might need to upgrade the firmware to a more recent version, though this possibly gives me a clue to a bug on my end with the editor.

Latest firmware is **2.1.0**, and you can [download it here](https://github.com/16n-faderbank/16n/releases) - you just need `16n_v210.hex`. [Instructions for updating are here](https://github.com/16n-faderbank/16n/wiki/Firmware:-installation-instructions) - you just need to download a piece of software called Teensy Loader, hook up your 16n, and flash it - you don't need to compile any code or anything.

If you can upgrade it to 2.1.0, that'd help me continue debugging.

Photozik, 2021-03-23:
ok. Great !
I will do that and tell you.
Thanks.

Photozik, 2021-03-23:
It seems to work now ! The 16n interface is on.
I just see that some faders go from 0 to 122, and some from 0 to 123.

infovore, 2021-03-23:
That's great. OK, so what you've got is a minor calibration that needs doing, which is what the editor's for. Plug in your 16n and in the editor, click Edit Config, then go to the Device Options tab. The "maximum raw value" might be set to 8135. Make that number a bit smaller - start with about 8000, I'm guessing - and hit "Update Controller" top right. Then, see how far the CC values alter. Keep bringing the "maximum raw value" down a bit until you get full 0-127 travel.

Photozik, 2021-03-23:
Done ! Every fader at 127 !

infovore, 2021-03-23:
Great news. I'm going to close this thread now, enjoy your faders!

Photozik, 2021-03-23:
Thanks a lot Tom !!!
Have a nice day.

Closed 2021-03-23.

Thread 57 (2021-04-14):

faderbank not recognized in configuration tool

godzillalaughs, 2021-04-14:
Build a fader bank from GitHub files.  Printed PCB though manufacturer, soldered all components.  Used firmware instructions and most current release.  Not being recognized in the config tool.  Am I missing something?

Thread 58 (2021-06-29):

A single fader outputs value 76 to 127 on a full travel

CarlosUnchained, 2021-06-29:
My fader 5 suddenly started to send values from 76 at minimum and 127 at maximum with linearity. The raw value was adjusted from 0 to 7850 so all faders would reach 127, but this behavior seems not to have anything to do with it.

Just updated to 2.1.0 hopping for a bug but it's not the case.

Could it be a bad soldered leg on that fader? I did it myself 2 years ago.
Any troubleshooting ideas would be welcomed!

CarlosUnchained, 2021-07-08:
So yes, it was a bad soldered leg on that fader. Solved :D

Closed 2021-07-08.

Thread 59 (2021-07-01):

CV outputs not 100% accurate

anemlife, 2021-07-01:
Hello,

First of all, sorry for posting there but I've been reaching Michigan Synth Work for my issue with 0 answers from them (my 16n was built by them).

I use the 16n faderbank mostly for the CV outputs and recently realized these were not going to full 5V. (I have to slightly offset the value with another module to reach a 100% wet value) The problem is: I don't own 16 offsets and it's getting a big issue for me! I already tried other USB cables/power sources thinking it could be the problem, but they all give the same results so this is probably not the issue.

Is there any workaround/solution for this? Thanks!

infovore, 2024-07-18:
Not really. The fader outputs draw power from your USB +5V line, which is meant to be around +5V but is more likely to be in the 4.90-5.00V region. The only way to avoid this is with external power, filtered down to exactly 5V; the Eurorack-capable revisions, such as the Sweet Sixteen or the AtoV rework will avoid this _as long as they are powered by 12V external_ (which will then be regulated down much more closely to 5V.

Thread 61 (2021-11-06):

Are 100mm faders possible?

mikattack, 2021-11-06:
**NOTE:** Not a hardware guy, don't know the complexity of this request.

I purchased a 16n from a maker and really liked it. When I asked whether having 100mm faders was possible, they said a PCB redesign would be necessary to implement that.

I'm opening this issue to see the viability of that.

The main desire here is more fine-grained control without a high amount of finger dexterity. With a longer throw range, the resulting values from the faders are more "spread out" and allow those of us with shaky or imprecise fingers to achieve smaller changes.

Hopefully that makes sense.

infovore, 2021-12-03:
Yep, your contact is right: it's very doable, but it requires a PCB redesign, because the faders are directly mounted to the board. You just need to redesign the PCB, moving everything around to accommodate the new 100mm fader parts, and then fab the board. It's not complex, because none of the circuits will change, just one part allocation, but it _is_ time-consuming, because of the number of things to move around.

16n, as it stands, uses 60mm faders. A 100mm version would be totally doable, but I'm not going to do that. It's exactly why I made the project open-source - so other people can remix the project to their needs. If the question is "is it possible", the answer is *yes*, definitely. If the question is "will you do it?" the answer is no. I'm going to close the issue because that feels like it answers the question?

mikattack, 2021-12-03:
Answer the question nicely. And the response is appreciated!

Closed 2021-12-03.

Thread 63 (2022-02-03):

Feature Request

jpnielsen, 2022-02-03:
Please make it possible to output 14-bit midi over USB.

I don't need [NRPN](https://en.wikipedia.org/wiki/NRPN), only the "fine adjustment" allready in the conventional MIDI controller specification, where any of the first 32 controls can be paired with a control offset 32 higher. I found an example [here](https://madskjeldgaard.dk/posts/14bit-midi-teensy-supercollider/):

fixed CC's are OK for me {0,1,2,3,4,5,6,7,8,9,10,11,12,13,14,15} paired with {32,33,34,35,36,37,38,39,40,41,42,43,44,45,46,47}.
 I plan on using it with VCV Rack 2

Cheers,
Jens Peter

Ps: I bought the AtoVReworked - and [asked ](https://github.com/AtoVproject/16n-AtoVproject-rework/issues/5)them too.

infovore, 2022-02-24:
Thanks for the request. It is not a trivial one: a large amount of the 16n firmware assumes that 7-bit data is being used everywhere. The internal data is filtered down to 7-bit quite early on in the analog read. To support this, we'd need to port to 14-bit everywhere, and then have a toggle to filter down, as well as update the MIDI output code.

It also would necessitate a patch to the editor, so as to ensure that CCs could be matched with pairing 'MSB' CCs correctly. I'm not interested in offering an alternative mode that has hardwired CCs, given the 'regular' mode is editable.

I'd welcome PRs to both editor and firmware that approach a solution, though, if someone wants to take it on.

Dewb, 2024-11-12:
I've been meaning to ask about appetite for a PR on this and somehow didn't see (or more likely, forgot about) this thread! I have been using this 14-bit branch for a while now https://github.com/16n-faderbank/16n/compare/main...Dewb:16n:14bitCC

It implements fixed CCs (0-31 paired with +32 higher), but I can tackle the editor patch as well to make it configurable.

Some questions about that:

1) Do you have any thoughts on how you'd prefer to see the configuration structure expanded? Asimple option would be to add two bytes for one bit per slider supporting a "14-bit mode" checkbox for each fader. But a more extensible approach might be to reserve a whole byte per fader for a "output format" enum that would initially just have options for standard CC or 14-bit CC, but could eventually allow for options like RPN, NRPN, pitch bend, etc.

2) I assume with the release of the 16nx, and the fact that the editor is shared between the two, that this feature would need to be added to the 16nx firmware as well (or disabled in the editor), right? I am planning on building a 16nx sometime this winter so I can tackle that too, though I wonder if it's as valuable in the 16nx since the DAC is only 12 bit. (I have some vague plans to try adding a 16-bit external DAC to my 16nx board order.)

infovore, 2024-11-13:
So, I appreciate the editor made things a little harder for hacking/futzing, so let me think out loud to document process:

- the memory map of the dataset is quite tight, and the memory map we use corresponds to the data being sent down the pipe over Sysex - ie, it splats the sysex data into EEPROM.
- EEPROM on a 3.2 is 128 bytes; on a 3.2 is 2048 bytes. Currently, on an nx - not the focus of this repo - the virtual EEPROM is set up as (IIRC) 256 bytes, but I could alter that.
- If we implement it with a 16-bit bitmask, a bool for each fader, to go "this fader is high-res", I think we have space. We warn the user if they've picked a 'conflicting" CC in the UI (eg: if you have set 32 to high res, and also picked 64, we need to warn you and stop you uploading config).
- this still changes the memory map, and would require _every_ 16n user to update their firmware in order to continue using the editor. To my mind, that is a **big** ask and not one I'd take lightly. (Later in this post I might see a way around this)

Here's the other thing: I personally am not convinced 14-bit data is reasonable with the hardware provided. Let me argue with myself:

- the fader is 60mm.
- with 16384 steps, that equates a step to 3 micrometers, assuming there's no jitter/noise.
- the Teensy ADC is 14-bit, yes, but realistically, that means somewhere between 10-12 _usable_ bits of data as a rule of thumb. I genuinely think two of those bits just disappear to noise/mechanical jitter. So whilst I could give you 14-bit data, I think it's meaningless.
- I definitely appreciate that it beats _7 bit_ data, which is not many steps for smooth musical control, and below the spec of the ADC. But a 14-bit ADC doesn't guarantee 14 bits of usable data. But yes, > 7 bits is definitely desirable and possible

That said: 10 bits of usable data, scaled up to 14 (`<<4`) is still notable smoother than 7 bits (0-127) of the CC spec. That logic means this still _could_ work with the 12-bit ADC of the RP2040 in the 16nx: read 12 bits of data, bit-shift it up, noise aside, it's still a higher-res improvement on the 7-bit data.

Adding two bytes to the data payload is a reasonable ask there; the editor tweak is a faff but doable. There's also a way I can see to keep some backwards compatibility, but I need to think about that harder.

So: I'm actually inclined to explore this now I've argued myself into the two-bit version. I'm also happy to explore in parallel with 16nx. And it might be an opportunity to port the editor to Svelte 5, replace some ungainly stores with runed variables.

Interesting. This week I'm jam-packed but it could be a thing we explore. @Dewb , what do you think?

Dewb, 2024-11-14:
Awesome! Yes, I'm happy to iterate on this on whatever timeline. I've been sitting on this for a while so no urgency, but lately I'm trying to make an effort to finish & upstream dangling projects like this.

I do think we have empirical evidence that the 14-bit data is valuable, despite the limitations of the hardware, from all the Teletype i2c users. I'm one, and I'm pretty happy with it -- you definitely can't reliably hit a specific integer in the 0-16383 range, but it's smoother than 12 bits. (Isn't the Teensy 3.2 DAC 16-bit, with 13 bits usable?) If it's useful for Teletype users I don't see why MIDI users shouldn't also have the option on Teensy hardware. And yes, exactly, even if it's only 10 or 12 bits usable with the RP2040, a left-shifted 14-bit message is still appropriate for full-scale parameter mapping.

The editor backward compatibility issue seems solvable. You've already got a version field in the config struct/type, and if the editor always requests configuration before sending configuration, you could select the appropriate configuration struct and hide/show UI based on what the firmware supports. This of course makes the editor a little more complicated, but that seems inevitable unless the featureset remains static.

infovore, 2024-11-14:
@Dewb You're right, the editor could version features relatively easily - and actually also do stuff per device. We do actually have a config data per device that says what it's capable of, so it's easy to add "supports hi-res output".

I'd like to take this on, I think, it's a nice way to refresh the editor code a little.

I'm also agreed on the idea that 14-bit output is not about 14-bit adcs, or 14 bits of information; it's about more than 7 bits of information.

And I am happy that this can be added with minimal impact to older devices.

It's likely the bitmask will be inverse, simply because `0xFF` is the default state of erased memory... making it not necessary to write new bitmasks for every device.

Dewb, 2024-11-14:
Great! So you'll handle the editor work? I can update my branch with the proposed config struct change and draft a PR.

Dewb, 2024-11-15:
Couple of observations now that I've done a pass over the code:
* it's four additional bytes, not two, because we need the flags for both USB and TRS;
* four bytes isn't enough if the EEPROM layout and the sysex messages are identical, because each byte of the sysex payload has to have its high bit low.

Having said that though, I took a stab at the config support (code here: https://github.com/16n-faderbank/16n/commit/d7a6d8d00aa22216189245f6d36f340dc8daf5c5), and aside from the high bit problem, this strategy appears to work fine in limited testing (sending sysex from Max to configure.) By adding a check if the sysex message is shorter than expected, I can still use the existing editor to configure everything except the new flags.

infovore, 2024-11-15:
@Dewb thank you! This is looking interesting. I agree on four extra bytes, absolutely fine with that, still fits into memory on a Teensy LC.

So this is probably going to take longer to merge in than you'd like, but here's what I propose:

- I work out a way of adding this into the editor elegantly, whilst also possibly patching the editor / giving it a good overhaul. (It feels like a worthwhile time to do this). It'll probably look like a checkbox on each column, and then updating the display to work displaying high-res fader values/debugging, which is a bit harder. I also gate the feature behind a firmware-version on the device (which is not something implemented yet).
- With that done, we review the PR and see if it all plays ball
- Simultaneously, I work on a similar patch for `16nx`
- Release the lot together.

I'll be honest and say I'm quite chocka right now, but also quite enthuisastic as a way into this, and it looks like your PR is in a really good place, so it's something nice to frame the editor against.

Dewb, 2024-11-15:
Awesome! Again, no rush. If we get confident in the sysex layout, I could release the 14-bit support in VCV Rack before the editor is finalized (Rack could handle setting the 14-bit flags as requested.)

If the editor will keep you busy, I can probably also take a swing at the 16nx firmware changes once I get around to building one.

We do need to solve point 2 above though, I should have called that out more clearly. With a 16 bit field we can’t send that over sysex as two bytes; the high bits have to be zero, so it’s impossible to set fader 8 or 16 high in the bit field. I see a couple strategies: the bit field could be split into 3 or 4 bytes instead of 2, or the bitfield could remain densely packed in EEPROM and it could be split across twice as many bytes when going in and out over sysex. The latter would be more space efficient, but it would make the sysex de/serialization code more complex.

Dewb, 2024-11-16:
Another possible solution: there are 4 unused bits in each channel config byte, since 0-15 only uses the lower four bits. The unused top four bits could become a "mode" enum for each channel, where 0000 is normal CC, 0001 is 14-bit CC, and other values could be reserved for future pitch bend/NRPN support, etc. Then this change wouldn't consume any additional space. The only risk is that any software that interprets the 16n sysex that isn't already ignoring those top bits / constraining the channel byte to legal values will need to be updated.

Dewb, 2024-11-16:
Ah, it looks like MIDI channel is being stored as 1-16, not 0-15, so that only leaves two unused bits.

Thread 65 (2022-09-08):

16n as sequencer

FantacciSimone, 2022-09-08:
One of the main characteristics of the 16n is that (obviously) all the output signals are simultaneous; this makes the 16n a controller and nothing more.

What would happen if the output signals (at least MIDI out) were sequential at regular clock intervals (from MIDI in)? It would become a real sequencer. The sliders could adjust 16 pitches by 16 steps ... or maybe 8 for the pitch and 8 for the velocity.

Daydream or could we really give new life to our beloved faderbank?

Pilzfuss, 2022-09-29:
This would be heavily awesome !

FantacciSimone, 2022-09-29:
In the meantime I have discovered this fantastic script for Norns, which is very close to what I dreamed of!
https://github.com/zjb-s/sempra/tree/main

ArthurGibert, 2024-05-08:
There is now a eurorack expander that allows that. Reads the fader values with i2c thru a stereo cable for CV values.
https://random-works.co.uk/

infovore, 2024-07-18:
It's a nice feature suggestion, but a stretch to fit in the current firmware. Alternative firmware, taking midi clock, and emitting notes, would be possible - though the nQuencer, as linked above, does do this very well, including rest/tie handling I believe. It feels like a problem better solved by Norns, Max4Live, or other hardware, than being core featureset of the faderbank.

Closed 2024-07-18.

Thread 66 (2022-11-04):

v2.1.0 with LC not connecting to web editor

tonyjmorton, 2022-11-04:
I've replaced a broken 3.2 in my 16n with an LC. The V2.1.0 firmware loads successfully and sends MIDI as expected. However, it won't connect to the web editor. I've checked with Ableton and the device comes up as "Teensy MIDI", not "16n."

I then flashing the V2.0.1 which does show up in the web editor, however the first fader won't work. Checking the device name in Ableton correctly displays "16n."

Any help would be greatly appreciated!

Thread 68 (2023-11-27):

Teensy 3.2 -> 4.0 Migration

janczmok1970, 2023-11-27:
Hi,
i wonder what functions are critical in the 3.2 that would stop to 4.0 migration ?
Background: I hardly can get a 3.2, but 4.0 seems pin compatible.

eagereyes, 2024-03-21:
I just built a 16n using a Teensy 4.0 and it works with basically no modifications. I just commented out all the I2C code because the i2c_t3 library doesn't exist on 4.0 and I don't need I2C anyway.

That aside, it works just fine if I set the maximum raw value in the config utility to 4090. I bet there's a setting somewhere to get higher resolution, but since we're only sending 7-bit values anyway, it doesn't matter.

eagereyes, 2024-06-02:
Hi, I've forked the repo and uploaded my modified version of the firmware here: https://github.com/eagereyes/16n-for-Teensy-4.0 It also includes a compiled .hex file for use on Teensy 4.0. Let me know if it works for you!

Cy-Rot, 2024-06-16:
Hi, the hex file works fine, but I can't compile the source code.
I was on an older version of the arduino Ide, wich raised a lot of errors with midi.h.

I upgraded to 2.3.2 now but there are still a lot of warnings concerning sign and unsigned values and one ( as I assume) one error, which prohibits the teensy from connecting as a usb midi interface to my computer:
********************************************************************************************************************************
__In file included from C:\Users\samoz\AppData\Local\Arduino15\packages\teensy\hardware\avr\1.59.0\libraries\MIDI\src/MIDI.h:307,
from C:\_DATEN\05_THO\CyFader\Cy_16n-for-Teensy-4.0main\firmware\16n_faderbank_firmware\16n_faderbank_firmware.ino:22:
C:\Users\samoz\AppData\Local\Arduino15\packages\teensy\hardware\avr\1.59.0\libraries\MIDI\src/MIDI.hpp:492:74: note:   initializing argument 1 of 'void midi::MidiInterface<Transport, _Settings, _Platform>::sendRealTime(midi::MidiType) [with Transport = midi::SerialMIDI<HardwareSerial>; _Settings = midi::DefaultSettings; _Platform = midi::DefaultPlatform]'
  492 | void MidiInterface<Transport, Settings, Platform>::sendRealTime(MidiType inType)
      |                                                                 ~~~~~~~~~^~~~~~_
*********************************************************************************************************************************

Maybe you've have an idea how I could solve this?

infovore, 2024-07-18:
I believe 4.0 is pin compatible; the firmware will require recompiling. The hex file linked above by @eagereyes might be your best bet. Meanwhile, I've also [made a branch that reverts to using Wire.h](https://github.com/16n-faderbank/16n/tree/teensy4.0_spiking); the main advantage of that would be that Teensy 4 boards could be used along with I2C.

I do not, however, have a Teensy 4.0 to test with.

miotislucifugis, 2025-04-13:
For my port of the telex teletype expander code to teensy 4.0   [https://github.com/miotislucifugis/Telex_teensy4?tab=readme-ov-file](url) it turned out the fix was stupidly simple: just swap the I2C library for one that is compatible with teensy 4.x!    that was pretty much it, and was essentially a drop in replacement.   I first tried with Wire, and while it worked, it wasnt fast enough and would eventually cause I2c glitches where devices would stop responding.    I ultimately used this library:  https://github.com/Richard-Gemmell/teensy4_i2c .    Like I2C t3,  it is wire-compatible and pretty much uses the same callbacks.   Only the setup, needs to be modified slightly, as I2C t3 has a few extra variables.  ( teensy4_i2c has the same setup variables as wire)

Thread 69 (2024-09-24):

N16 not working

DanLeuca, 2024-09-24:
I have bought a N16 built by someone else but it does not work... when moving the faders the LED blinks but the computer would not 'see' the faderbank at all, so I cannot load the config files...

infovore, 2024-10-03:
Immediate question: is the USB micro-type-B cable you're using a cable that transmits data? A lot of use have USB micro cables lying around from, eg, mobile phone chargers that only have the power lines wired.

The LED flashing just indicates that the device is emitting MIDI; it's no indication of any actual connection.

Also - does it even appear over USB in some kind of System Information tool (I forget where you'd find this on Windows, on MacOS it's Apple Menu -> Hold Option -> System Information, and see if it's on one of the USB buses). If it's not showing up there, my first thought is: dud cable.

DanLeuca, 2024-10-04:
Thank you very much for your help. Do you know the exact name for the cable, have you got a link to some good product/supplier! Thanks in advance. Regards,Dan Sent from my iPhoneOn 3 Oct 2024, at 10:07, Tom Armitage ***@***.***> wrote:
Immediate question: is the USB micro-type-B cable you're using a cable that transmits data? A lot of use have USB micro cables lying around from, eg, mobile phone chargers that only have the power lines wired.
The LED flashing just indicates that the device is emitting MIDI; it's no indication of any actual connection.
Also - does it even appear over USB in some kind of System Information tool (I forget where you'd find this on Windows, on MacOS it's Apple Menu -> Hold Option -> System Information, and see if it's on one of the USB buses). If it's not showing up there, my first thought is: dud cable.

—Reply to this email directly, view it on GitHub, or unsubscribe.You are receiving this because you authored the thread.Message ID: ***@***.***>

infovore, 2024-10-07:
Honestly, as long as the cable description mentions data transfer, you're good. Eg, an Amazon Basics one should be absolutely fine. Just choose the correct connector for your device - USB-A or USB-C, with USB micro-B at the other end, and you should be good. You don't need to spend lots (and of course, it might _not_ be the cable. But a new cable is cheaper than a cable tester...)

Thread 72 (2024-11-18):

Compilation error: CD74HC4067.h: No such file or directory

mr-sibs, 2024-11-18:
Hello, when trying to flash the fimware I get the following warning Compilation error: CD74HC4067.h: No such file or directory

infovore, 2024-11-19:
As the `README` says, you need the `CD74HC4067` library installed; you can install it using the Arduino IDE's Library Manager.

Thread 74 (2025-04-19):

Tried flashing with loader, now board no longer lights up and controller is not recognized

shocktropics, 2025-04-19:
I recently picked up a 16n that, while recognized by my DAW with corresponding orange LED, was not recognized by the online Editor. I tried following instructions for flashing the latest firmware, which worked fine with the Teensy Loader and the hex file etc.

The thing is, after it finished loading and rebooting, the 16n no longer has an orange LED no matter what I do, and it doesnt seem to be on at all.

Did I brick it somehow? Please help! These things are integral to my work!

shocktropics, 2025-04-19:
I have gone through the teensy loader firmware blinking a couple additional times. The loader seems to recognize when I push the little reset button on the board, and flashes firmware, automatically reboots, etc. Seems to be all good...but the 16n itself still has no LED activity, and is not recognized by the editor or the DAW or anything...!

shocktropics, 2025-04-19:
UPDATE: I seem to have gotten it sorted out! Through trial and error with the teensy loader app, I found that the board that is an "LC", and I found a corresponding firmware, flashed it again, and now everything seems to be good.

shocktropics, 2025-04-19:
another update: while the 16n now seems to be working fine within the DAW, it is still not recognized by the web editor...hmmm

infovore, 2025-04-21:
We're having issues with 2.2.0 with LC boards.

https://github.com/16n-faderbank/16n/releases/tag/v2.1.1

2.1.1 should remain compatible with LC boards - there are links to LC binaries there. You haven't bricked your 16n.

shocktropics, 2025-04-22:
thank you for the response. Through trial and error I indeed discovered that the particular 16n was an LC board, and subsequently I flashed the correct 2.1.1 firmware and it works fine.

Does its non-recognition thru the web editor correspond to issues with the LC board as well?

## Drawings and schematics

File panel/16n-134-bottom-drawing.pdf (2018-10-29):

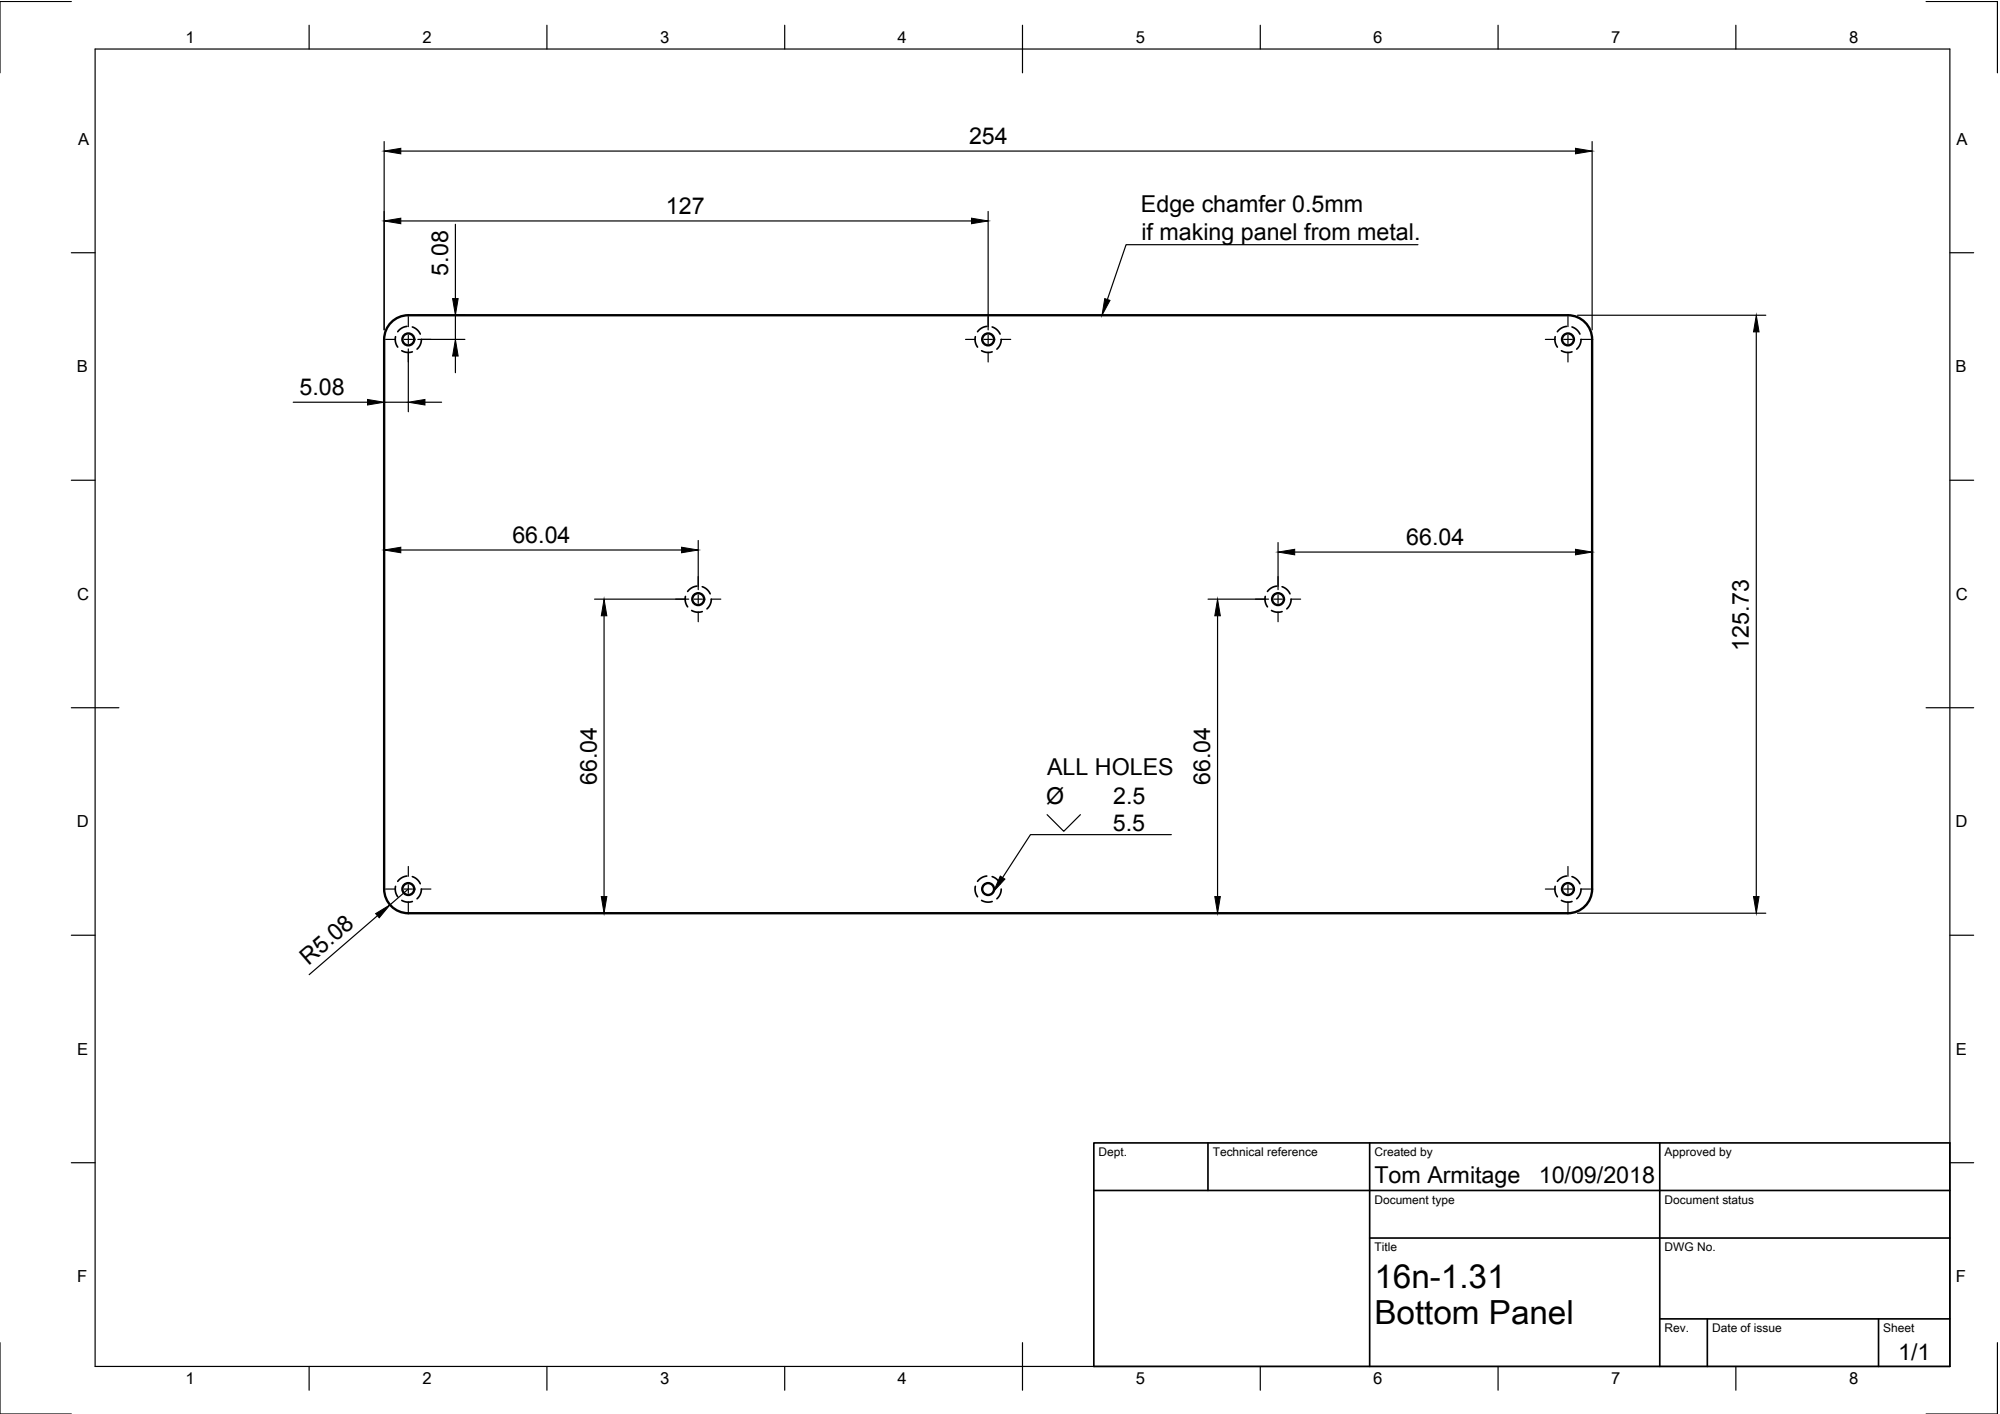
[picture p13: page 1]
Tom Armitage; 66.04 ALL HOLES

Edge chamfer 0.5mm
if making panel from metal.

Dept. | Technical reference | Created by 10/09/2018 | Approved by

Document type | Document status

Title 16n-1.31 Bottom Panel | DWG No.

Rev. | Date of issue | Sheet 1/1

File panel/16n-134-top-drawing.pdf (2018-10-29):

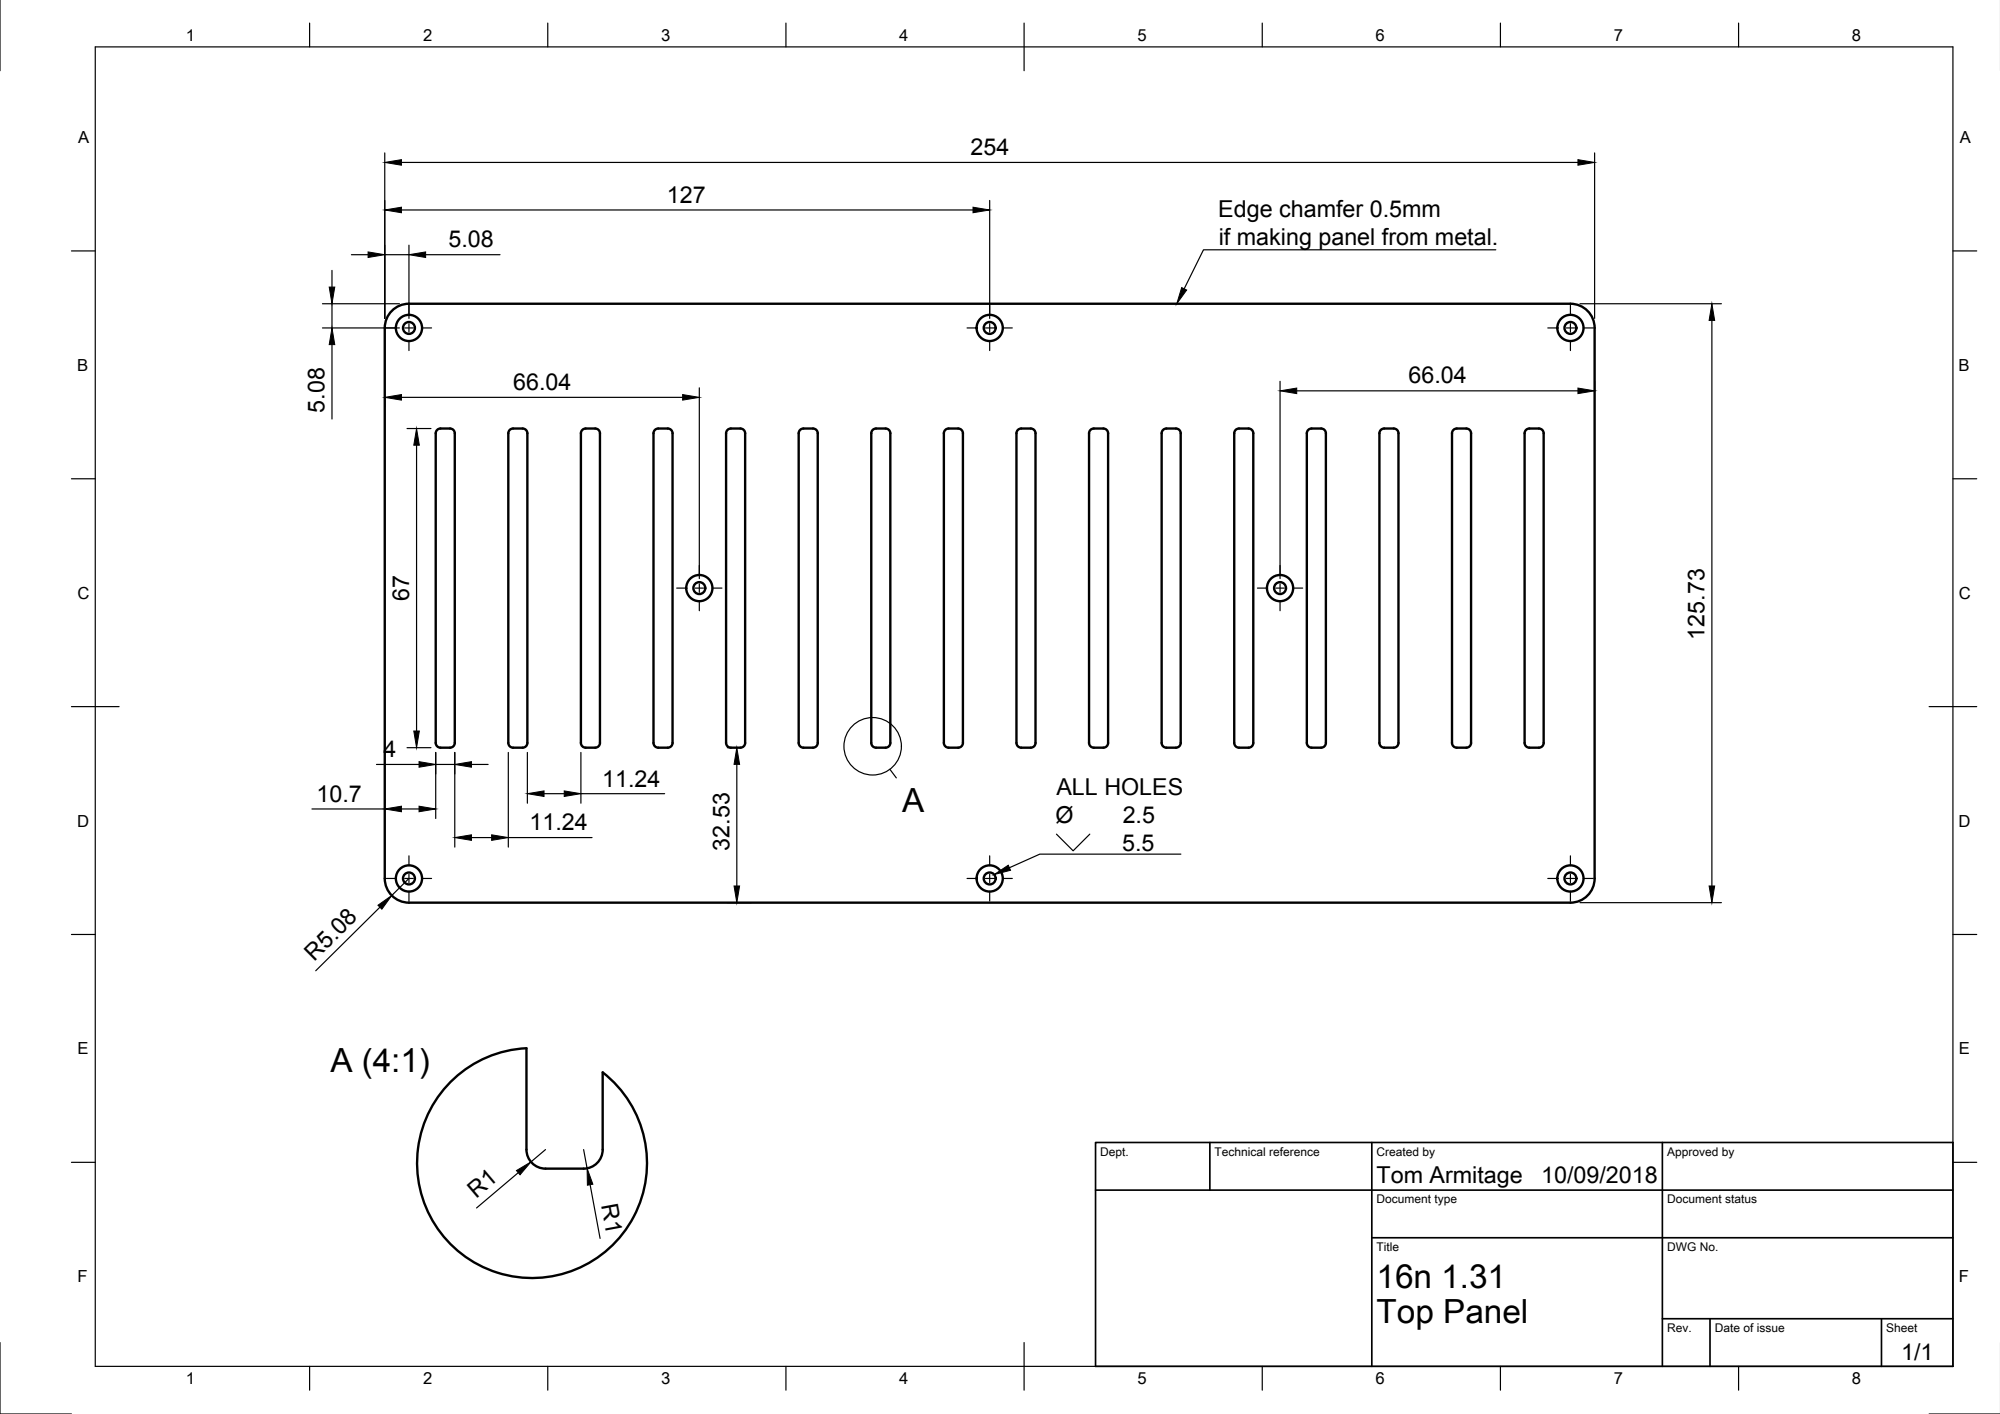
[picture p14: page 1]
ALL HOLES

Edge chamfer 0.5mm
if making panel from metal.

Dept. | Technical reference | Created by Tom Armitage 10/09/2018 | Approved by

Document type | Document status

Title 16n 1.31 Top Panel | DWG No.

Rev. | Date of issue | Sheet 1/1

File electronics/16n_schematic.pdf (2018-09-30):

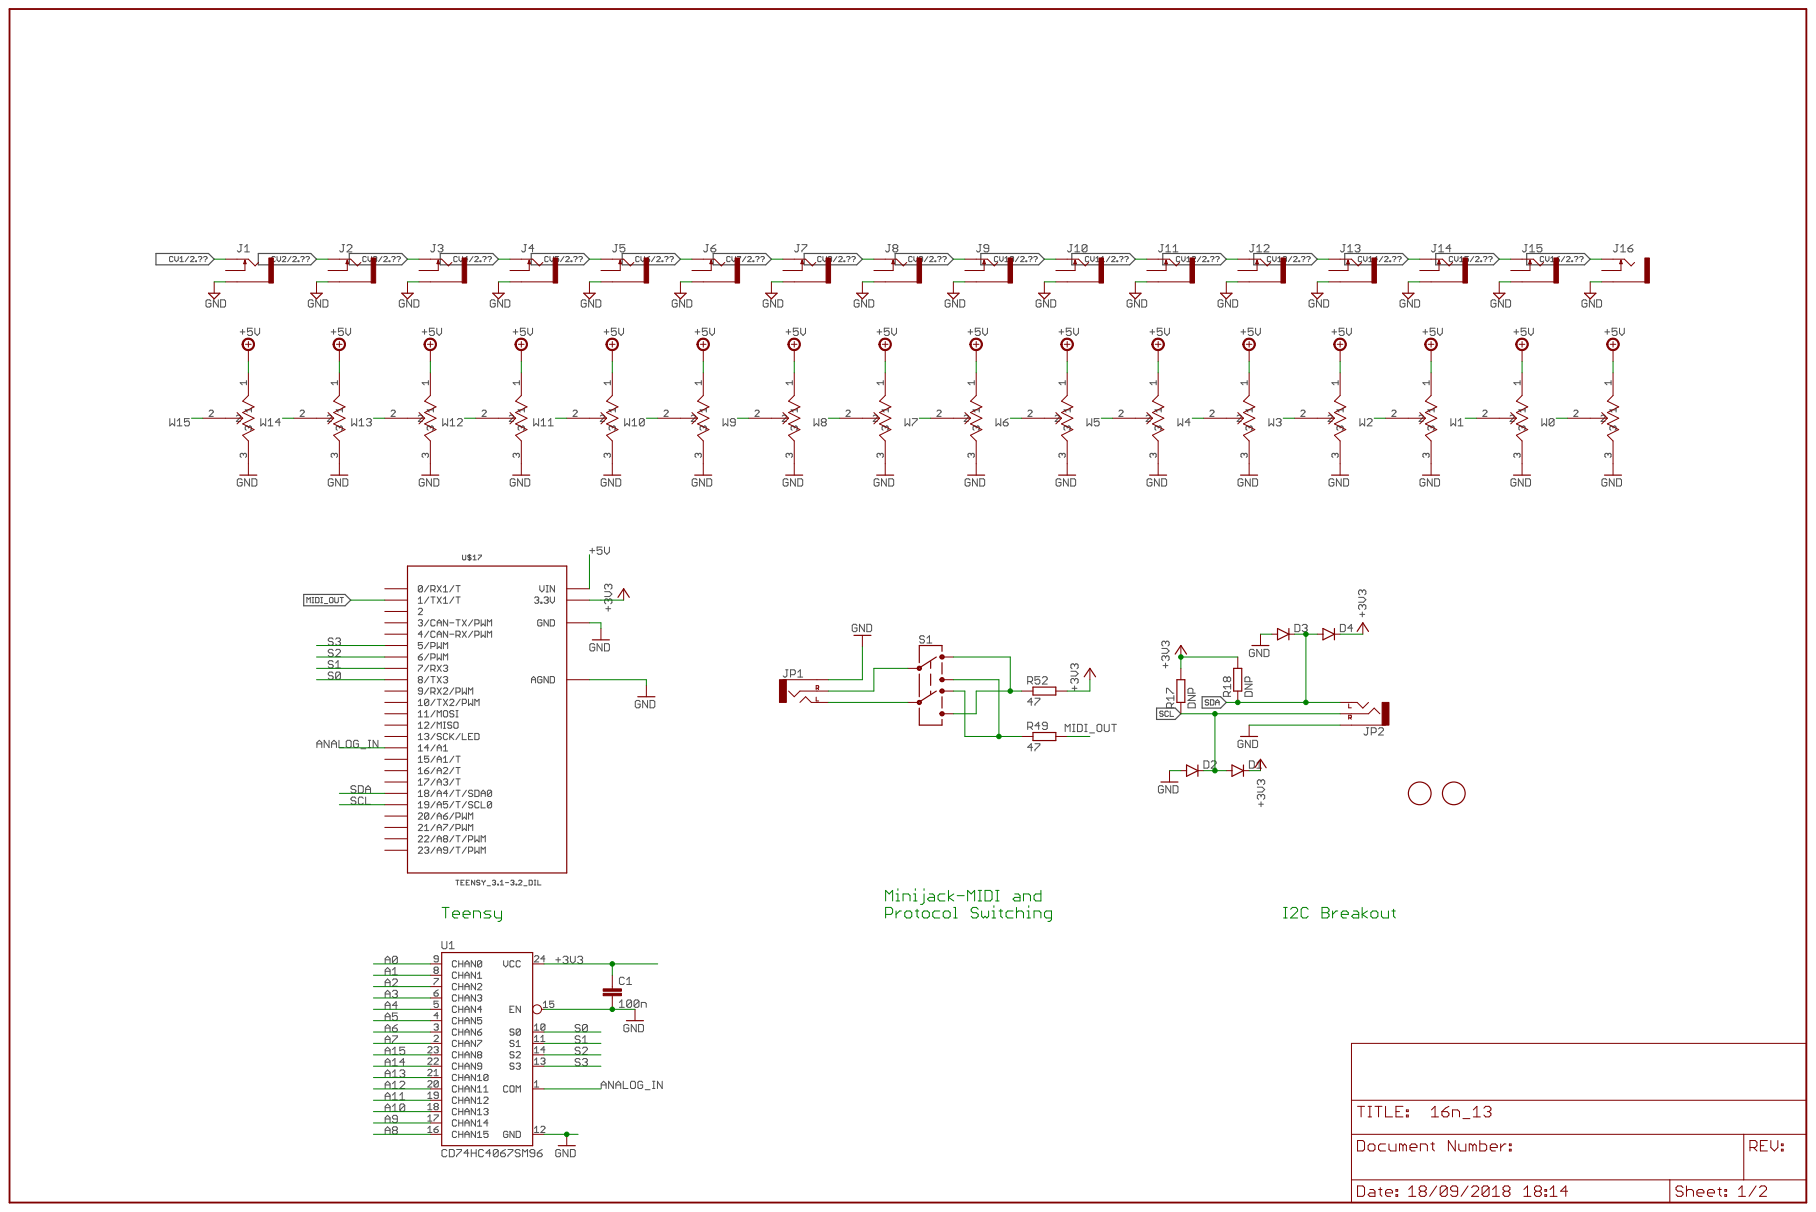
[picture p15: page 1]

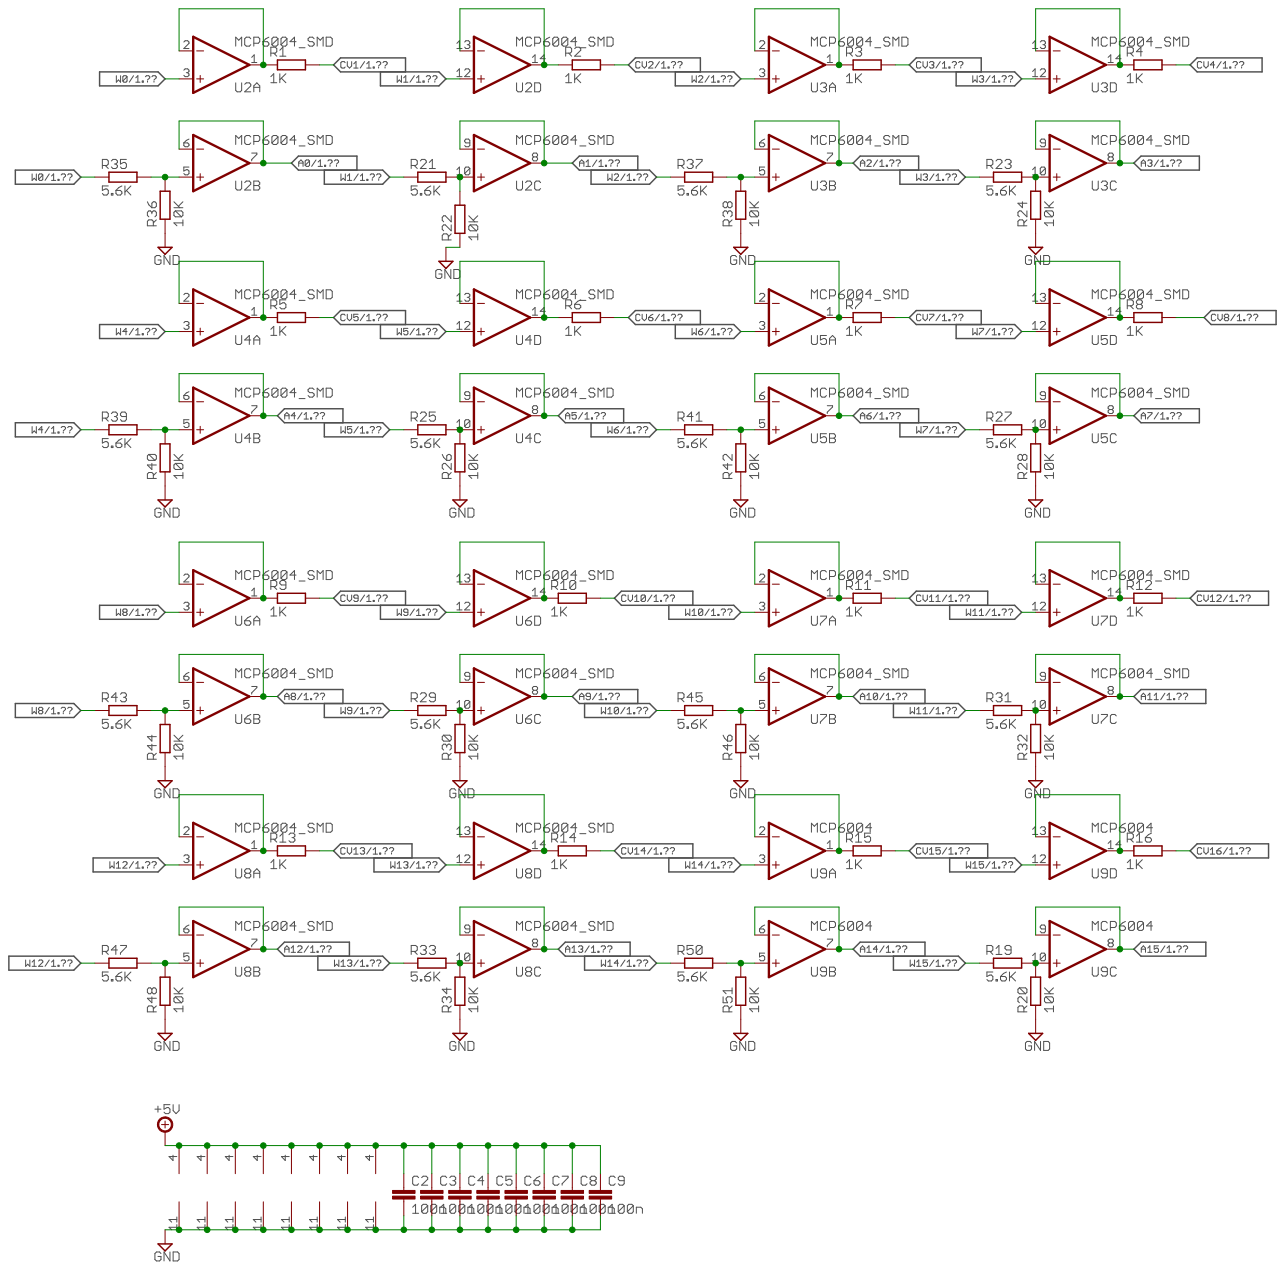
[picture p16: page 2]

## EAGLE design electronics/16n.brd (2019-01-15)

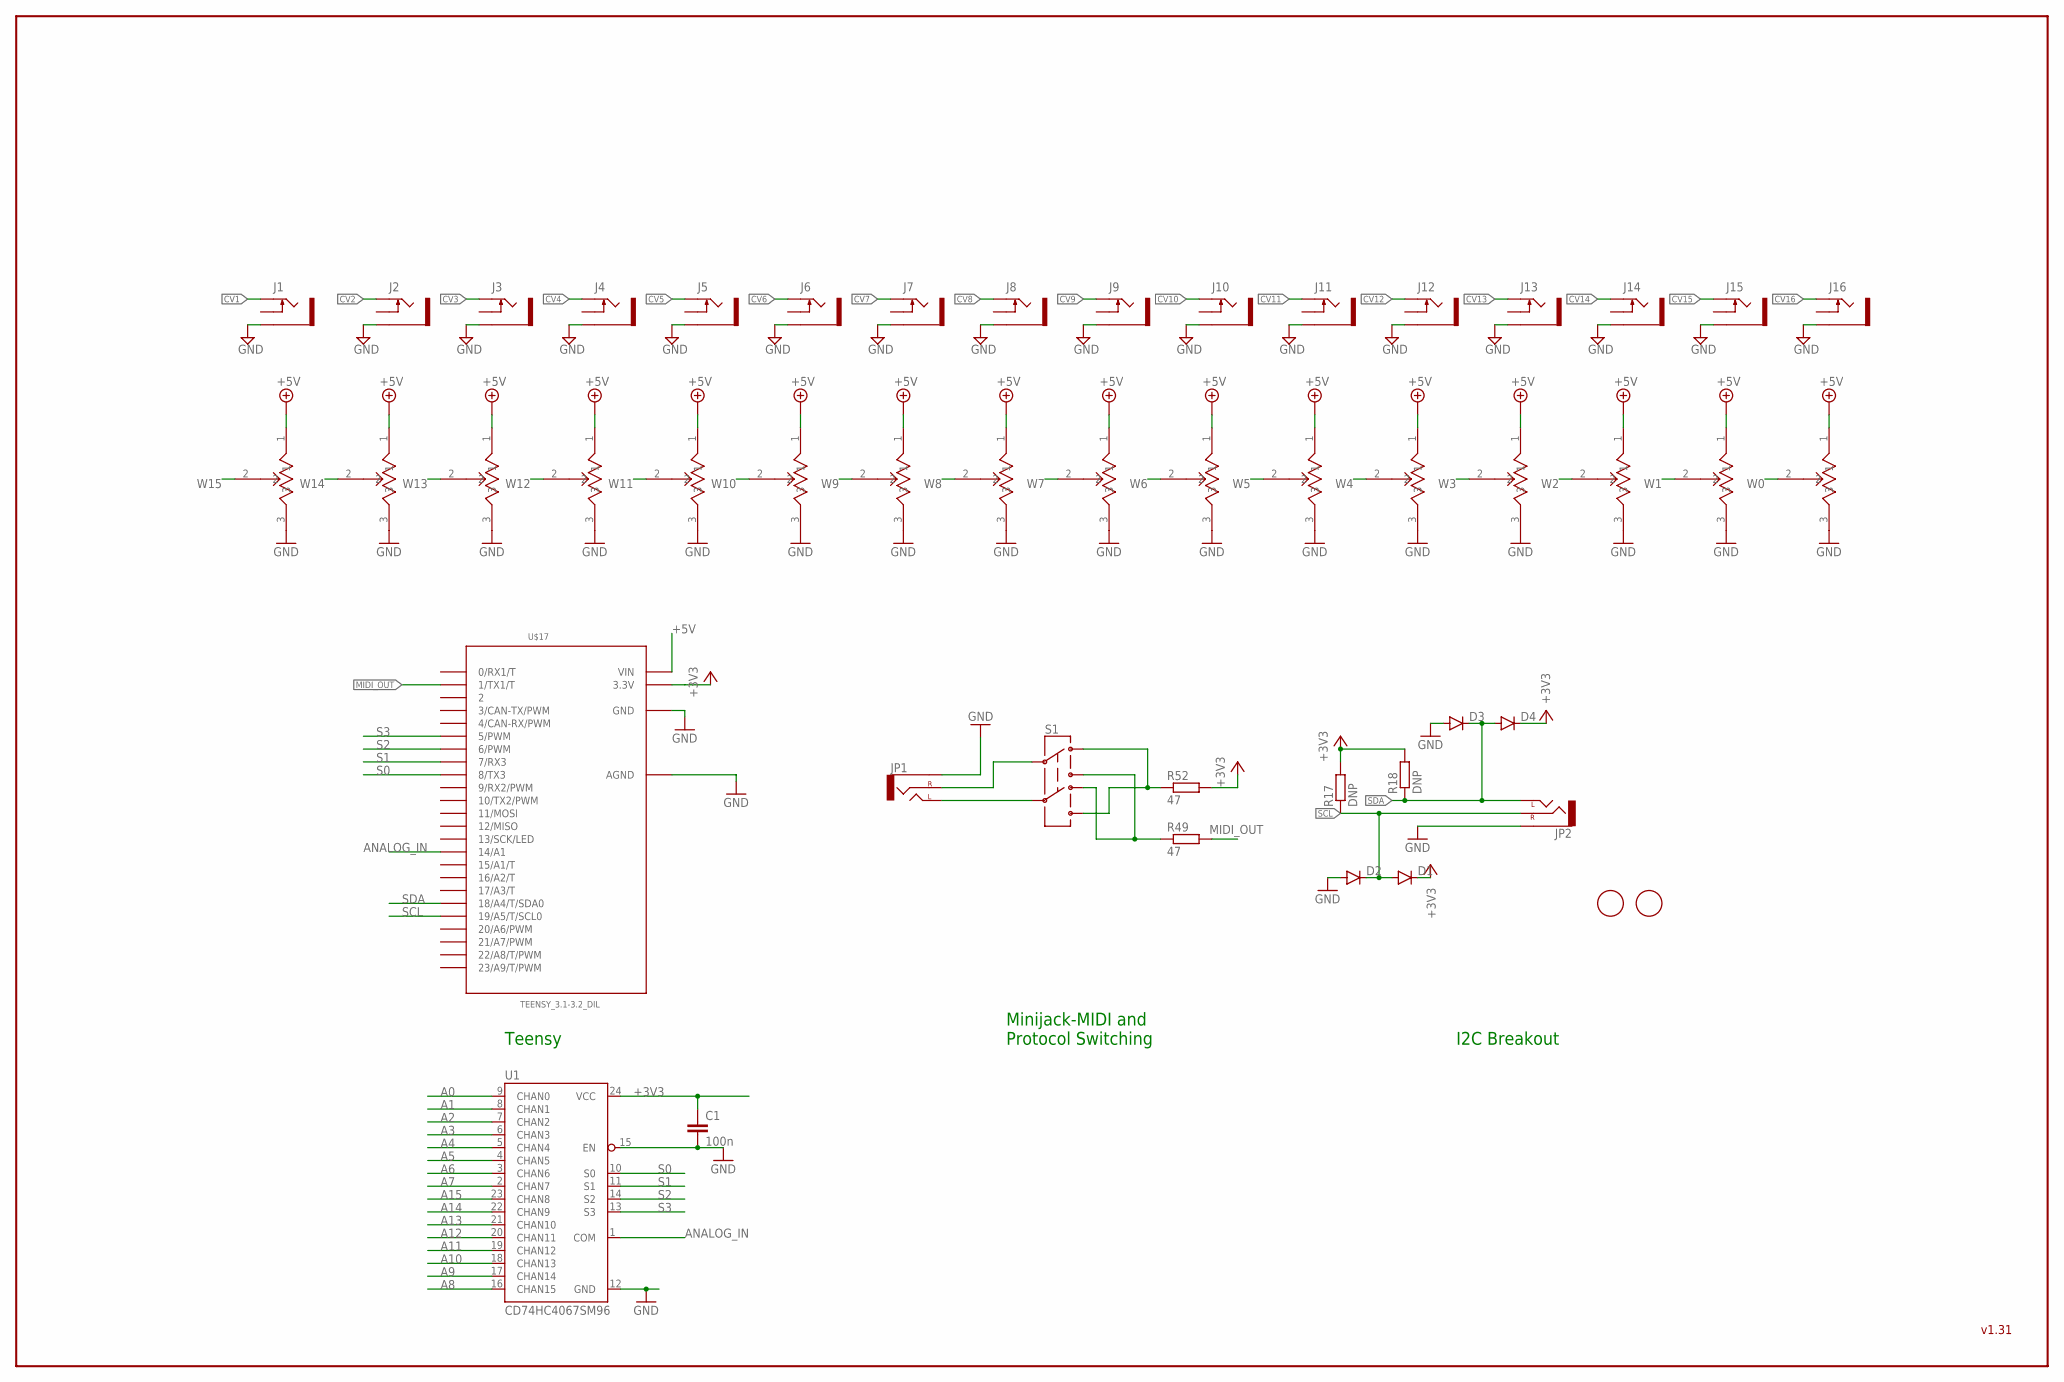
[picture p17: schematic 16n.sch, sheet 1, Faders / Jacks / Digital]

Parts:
C1: 100n; C0805
D1, D2, D3, D4: DIODESOD123; SOD-123
FID1, FID2: FIDUCIAL; FIDUCIAL_1MM
J1, J2, J3, J4, J5, J6, J7, J8, J9, J10, J11, J12, J13, J14, J15, J16: PJ302M
JP1, JP2: AUDIO-JACKPTH; AUDIO-JACK
R17, R18: DNP; R0805
R49, R52: 47; R0805
S1: SWITCH-DPDTEG2211; EG2211
U1: CD74HC4067SM96; SOIC127P1030X265-24
U$1, U$2, U$3, U$4, U$5, U$6, U$7, U$8, U$9, U$10, U$11, U$12, U$13, U$14, U$15, U$16: SLIDEPOT-ALPS-60MM; RS6011SP600
U$17: TEENSY_3.1-3.2_DIL; TEENSY_3.0-3.2&LC_DIL

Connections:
+3V3: C1.1, D1.C, D4.C, R17.2, R18.2, R52.2, U1.24 (VCC), U$17.3.3V
+5V: U$1.1, U$2.1, U$3.1, U$4.1, U$5.1, U$6.1, U$7.1, U$8.1, U$9.1, U$10.1, U$11.1, U$12.1, U$13.1, U$14.1, U$15.1, U$16.1, U$17.VIN; also elsewhere on the board
A0: U1.9 (CHAN0); also elsewhere on the board
A1: U1.8 (CHAN1); also elsewhere on the board
A2: U1.7 (CHAN2); also elsewhere on the board
A3: U1.6 (CHAN3); also elsewhere on the board
A4: U1.5 (CHAN4); also elsewhere on the board
A5: U1.4 (CHAN5); also elsewhere on the board
A6: U1.3 (CHAN6); also elsewhere on the board
A7: U1.2 (CHAN7); also elsewhere on the board
A8: U1.16 (CHAN15); also elsewhere on the board
A9: U1.17 (CHAN14); also elsewhere on the board
A10: U1.18 (CHAN13); also elsewhere on the board
A11: U1.19 (CHAN12); also elsewhere on the board
A12: U1.20 (CHAN11); also elsewhere on the board
A13: U1.21 (CHAN10); also elsewhere on the board
A14: U1.22 (CHAN9); also elsewhere on the board
A15: U1.23 (CHAN8); also elsewhere on the board
ANALOG_IN: U1.1 (COM), U$17.14/A0 (14/A1)
CV1: J1.TIP; also elsewhere on the board
CV2: J2.TIP; also elsewhere on the board
CV3: J3.TIP; also elsewhere on the board
CV4: J4.TIP; also elsewhere on the board
CV5: J5.TIP; also elsewhere on the board
CV6: J6.TIP; also elsewhere on the board
CV7: J7.TIP; also elsewhere on the board
CV8: J8.TIP; also elsewhere on the board
CV9: J9.TIP; also elsewhere on the board
CV10: J10.TIP; also elsewhere on the board
CV11: J11.TIP; also elsewhere on the board
CV12: J12.TIP; also elsewhere on the board
CV13: J13.TIP; also elsewhere on the board
CV14: J14.TIP; also elsewhere on the board
CV15: J15.TIP; also elsewhere on the board
CV16: J16.TIP; also elsewhere on the board
GND: C1.2, D2.A, D3.A, J1.GND (SLEEVE), J2.GND (SLEEVE), J3.GND (SLEEVE), J4.GND (SLEEVE), J5.GND (SLEEVE), J6.GND (SLEEVE), J7.GND (SLEEVE), J8.GND (SLEEVE), J9.GND (SLEEVE), J10.GND (SLEEVE), J11.GND (SLEEVE), J12.GND (SLEEVE), J13.GND (SLEEVE), J14.GND (SLEEVE), J15.GND (SLEEVE), J16.GND (SLEEVE), JP1.SLEEVE, JP2.SLEEVE, U1.12 (GND), U1.15 (EN), U$1.3, U$2.3, U$3.3, U$4.3, U$5.3, U$6.3, U$7.3, U$8.3, U$9.3, U$10.3, U$11.3, U$12.3, U$13.3, U$14.3, U$15.3, U$16.3, U$17.AGND, U$17.GND; also elsewhere on the board
MIDI_OUT: R49.2, U$17.1 (1/TX1/T)
unnamed: JP1.TIP (LEFT), S1.P2 (5)
unnamed: JP1.RING (RIGHT), S1.P1 (2)
unnamed: R49.1, S1.P1-TB (3), S1.P2-TA (4)
unnamed: R52.1, S1.P1-TA (1), S1.P2-TB (6)
S0: U1.10 (S0), U$17.8 (8/TX3)
S1: U1.11 (S1), U$17.7 (7/RX3)
S2: U1.14 (S2), U$17.6 (6/PWM)
S3: U1.13 (S3), U$17.5 (5/PWM)
SCL: D1.A, D2.C, JP2.RING (RIGHT), R17.1, U$17.19/A5 (19/A5/T/SCL0)
SDA: D3.C, D4.A, JP2.TIP (LEFT), R18.1, U$17.18/A4 (18/A4/T/SDA0)
W0: U$1.2; also elsewhere on the board
W1: U$2.2; also elsewhere on the board
W2: U$3.2; also elsewhere on the board
W3: U$4.2; also elsewhere on the board
W4: U$5.2; also elsewhere on the board
W5: U$6.2; also elsewhere on the board
W6: U$7.2; also elsewhere on the board
W7: U$8.2; also elsewhere on the board
W8: U$9.2; also elsewhere on the board
W9: U$10.2; also elsewhere on the board
W10: U$11.2; also elsewhere on the board
W11: U$12.2; also elsewhere on the board
W12: U$13.2; also elsewhere on the board
W13: U$14.2; also elsewhere on the board
W14: U$15.2; also elsewhere on the board
W15: U$16.2; also elsewhere on the board

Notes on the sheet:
Teensy
Minijack-MIDI and Protocol Switching
I2C Breakout

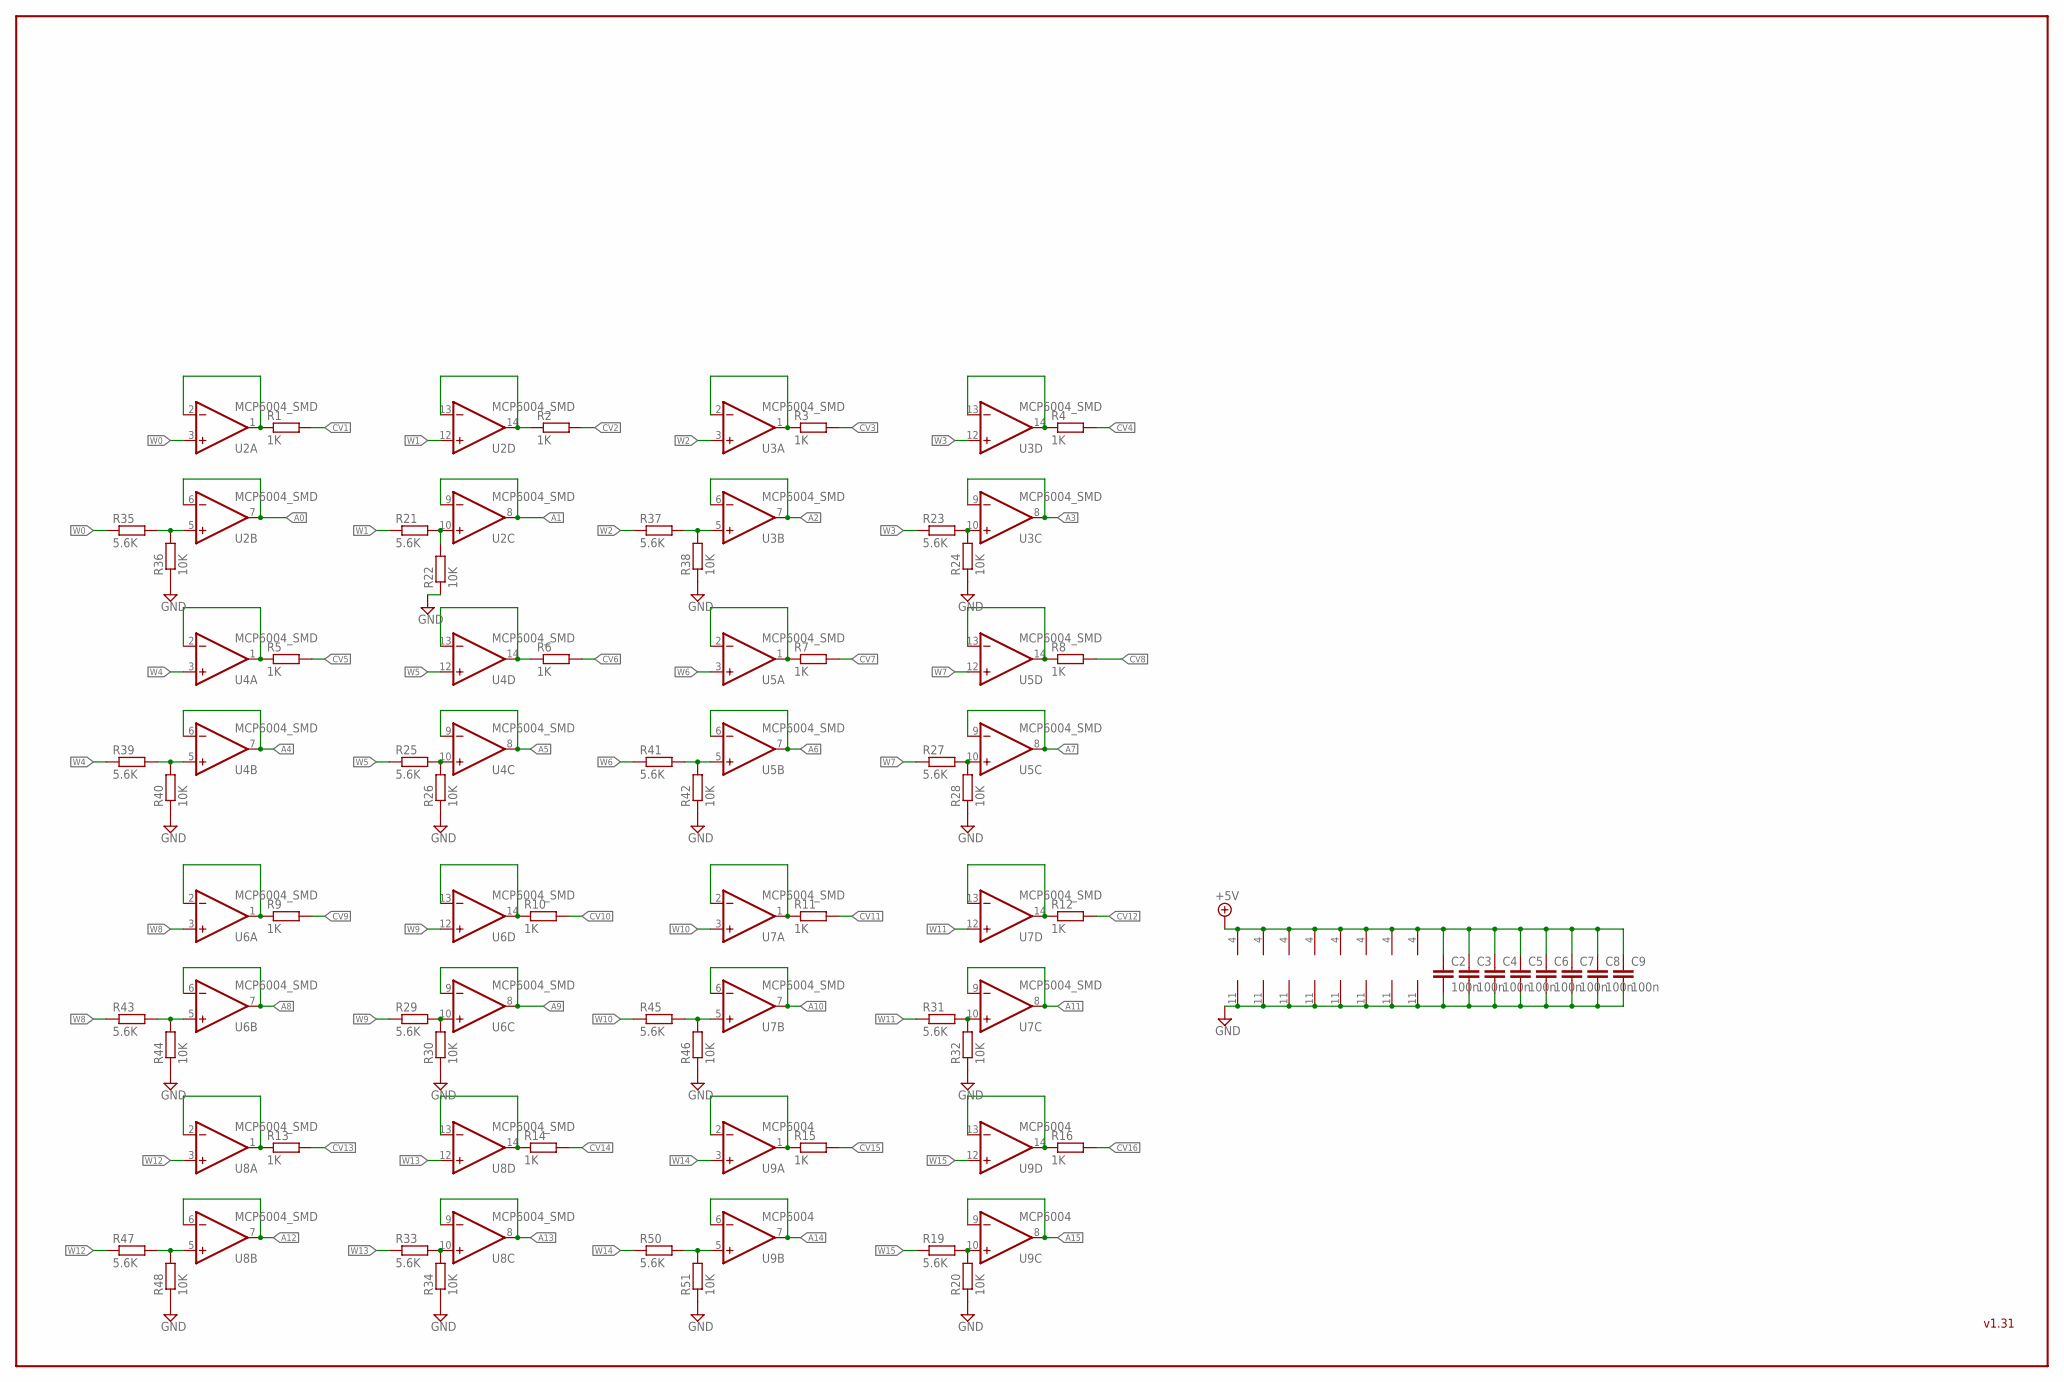
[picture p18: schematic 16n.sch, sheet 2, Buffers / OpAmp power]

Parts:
C2, C3, C4, C5, C6, C7, C8, C9: 100n; C0805
R1, R2, R3, R4, R5, R6, R7, R8, R9, R10, R11, R12, R13, R14, R15, R16: 1K; R0805
R19, R21, R23, R25, R27, R29, R31, R33, R35, R37, R39, R41, R43, R45, R47, R50: 5.6K; R0805
R20, R22, R24, R26, R28, R30, R32, R34, R36, R38, R40, R42, R44, R46, R48, R51: 10K; R0805
U2, U3, U4, U5, U6, U7, U8: MCP6004_SMD; SO14
U9: MCP6004; SO14

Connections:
+5V: C2.1, C3.1, C4.1, C5.1, C6.1, C7.1, C8.1, C9.1, U2.4 (V+), U3.4 (V+), U4.4 (V+), U5.4 (V+), U6.4 (V+), U7.4 (V+), U8.4 (V+), U9.4 (V+); also elsewhere on the board
A0: U2.6 (-IN), U2.7 (OUT); also elsewhere on the board
A1: U2.8 (OUT), U2.9 (-IN); also elsewhere on the board
A2: U3.6 (-IN), U3.7 (OUT); also elsewhere on the board
A3: U3.8 (OUT), U3.9 (-IN); also elsewhere on the board
A4: U4.6 (-IN), U4.7 (OUT); also elsewhere on the board
A5: U4.8 (OUT), U4.9 (-IN); also elsewhere on the board
A6: U5.6 (-IN), U5.7 (OUT); also elsewhere on the board
A7: U5.8 (OUT), U5.9 (-IN); also elsewhere on the board
A8: U6.6 (-IN), U6.7 (OUT); also elsewhere on the board
A9: U6.8 (OUT), U6.9 (-IN); also elsewhere on the board
A10: U7.6 (-IN), U7.7 (OUT); also elsewhere on the board
A11: U7.8 (OUT), U7.9 (-IN); also elsewhere on the board
A12: U8.6 (-IN), U8.7 (OUT); also elsewhere on the board
A13: U8.8 (OUT), U8.9 (-IN); also elsewhere on the board
A14: U9.6 (-IN), U9.7 (OUT); also elsewhere on the board
A15: U9.8 (OUT), U9.9 (-IN); also elsewhere on the board
CV1: R1.2; also elsewhere on the board
CV2: R2.2; also elsewhere on the board
CV3: R3.2; also elsewhere on the board
CV4: R4.2; also elsewhere on the board
CV5: R5.2; also elsewhere on the board
CV6: R6.2; also elsewhere on the board
CV7: R7.2; also elsewhere on the board
CV8: R8.2; also elsewhere on the board
CV9: R9.2; also elsewhere on the board
CV10: R10.2; also elsewhere on the board
CV11: R11.2; also elsewhere on the board
CV12: R12.2; also elsewhere on the board
CV13: R13.2; also elsewhere on the board
CV14: R14.2; also elsewhere on the board
CV15: R15.2; also elsewhere on the board
CV16: R16.2; also elsewhere on the board
GND: C2.2, C3.2, C4.2, C5.2, C6.2, C7.2, C8.2, C9.2, R20.1, R22.1, R24.1, R26.1, R28.1, R30.1, R32.1, R34.1, R36.1, R38.1, R40.1, R42.1, R44.1, R46.1, R48.1, R51.1, U2.11 (V-), U3.11 (V-), U4.11 (V-), U5.11 (V-), U6.11 (V-), U7.11 (V-), U8.11 (V-), U9.11 (V-); also elsewhere on the board
unnamed: R37.2, R38.2, U3.5 (+IN)
unnamed: R23.2, R24.2, U3.10 (+IN)
unnamed: R35.2, R36.2, U2.5 (+IN)
unnamed: R21.2, R22.2, U2.10 (+IN)
unnamed: R39.2, R40.2, U4.5 (+IN)
unnamed: R25.2, R26.2, U4.10 (+IN)
unnamed: R41.2, R42.2, U5.5 (+IN)
unnamed: R27.2, R28.2, U5.10 (+IN)
unnamed: R43.2, R44.2, U6.5 (+IN)
unnamed: R29.2, R30.2, U6.10 (+IN)
unnamed: R45.2, R46.2, U7.5 (+IN)
unnamed: R31.2, R32.2, U7.10 (+IN)
unnamed: R47.2, R48.2, U8.5 (+IN)
unnamed: R33.2, R34.2, U8.10 (+IN)
unnamed: R50.2, R51.2, U9.5 (+IN)
unnamed: R19.2, R20.2, U9.10 (+IN)
unnamed: R1.1, U2.1 (OUT), U2.2 (-IN)
unnamed: R2.1, U2.13 (-IN), U2.14 (OUT)
unnamed: R3.1, U3.1 (OUT), U3.2 (-IN)
unnamed: R4.1, U3.13 (-IN), U3.14 (OUT)
unnamed: R5.1, U4.1 (OUT), U4.2 (-IN)
unnamed: R6.1, U4.13 (-IN), U4.14 (OUT)
unnamed: R7.1, U5.1 (OUT), U5.2 (-IN)
unnamed: R8.1, U5.13 (-IN), U5.14 (OUT)
unnamed: R9.1, U6.1 (OUT), U6.2 (-IN)
unnamed: R10.1, U6.13 (-IN), U6.14 (OUT)
unnamed: R11.1, U7.1 (OUT), U7.2 (-IN)
unnamed: R12.1, U7.13 (-IN), U7.14 (OUT)
unnamed: R13.1, U8.1 (OUT), U8.2 (-IN)
unnamed: R14.1, U8.13 (-IN), U8.14 (OUT)
unnamed: R15.1, U9.1 (OUT), U9.2 (-IN)
unnamed: R16.1, U9.13 (-IN), U9.14 (OUT)
W0: R35.1, U2.3 (+IN); also elsewhere on the board
W1: R21.1, U2.12 (+IN); also elsewhere on the board
W2: R37.1, U3.3 (+IN); also elsewhere on the board
W3: R23.1, U3.12 (+IN); also elsewhere on the board
W4: R39.1, U4.3 (+IN); also elsewhere on the board
W5: R25.1, U4.12 (+IN); also elsewhere on the board
W6: R41.1, U5.3 (+IN); also elsewhere on the board
W7: R27.1, U5.12 (+IN); also elsewhere on the board
W8: R43.1, U6.3 (+IN); also elsewhere on the board
W9: R29.1, U6.12 (+IN); also elsewhere on the board
W10: R45.1, U7.3 (+IN); also elsewhere on the board
W11: R31.1, U7.12 (+IN); also elsewhere on the board
W12: R47.1, U8.3 (+IN); also elsewhere on the board
W13: R33.1, U8.12 (+IN); also elsewhere on the board
W14: R50.1, U9.3 (+IN); also elsewhere on the board
W15: R19.1, U9.12 (+IN); also elsewhere on the board

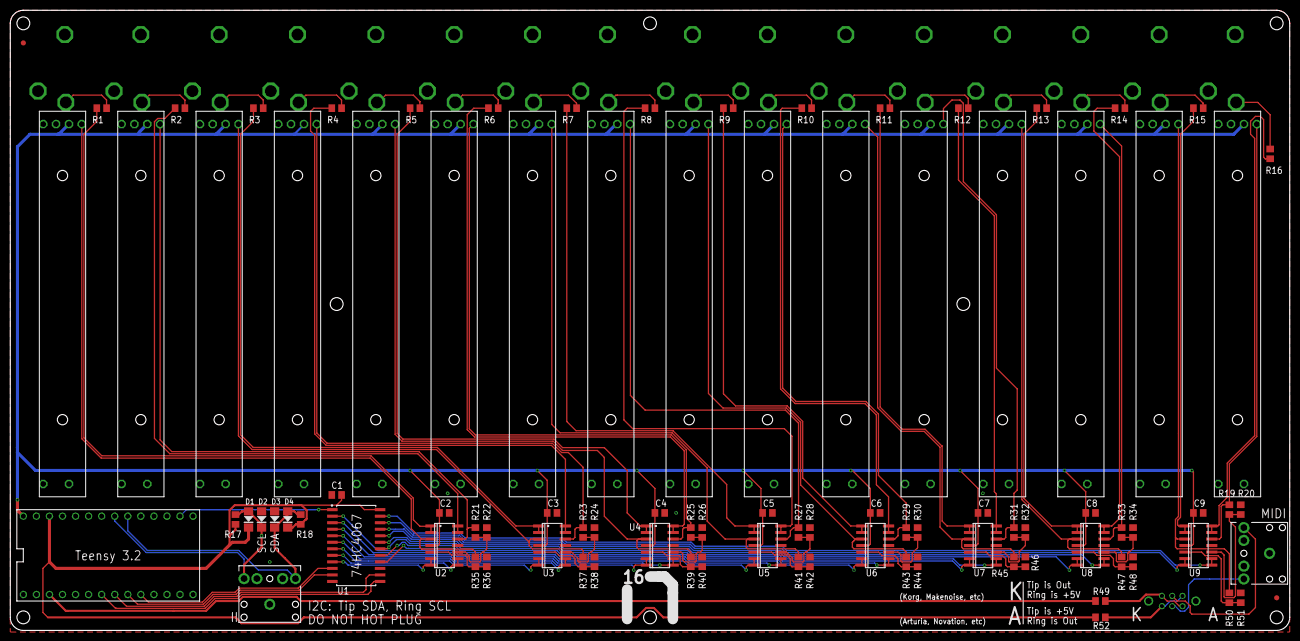
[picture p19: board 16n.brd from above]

Board: 2 copper layers, 248.9 x 120.7 mm, 112 parts (0 on the bottom side), 95 nets.

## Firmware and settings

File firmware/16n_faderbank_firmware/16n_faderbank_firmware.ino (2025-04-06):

/*
 * 16n Faderbank Firmware
 * (c) 2017,2018,2020 by Brian Crabtree, Sean Hellfritsch, Tom Armitage, and Brendon Cassidy
 * MIT License
 */

/*
 * NOTES:
 * - Hardware MIDI is on pin 1
 * - You **must** also compile this with Tools->USB type set to MIDI or MIDI/Serial (for debugging)
 * - You also should overclock to 120MHz to make it as snappy as possible
 */

/*
 * Most configuration now hpapens via online editor.
 * config.h is mainly for developer configuration.
 */

#include <CD74HC4067.h>
#include <EEPROM.h>
#include <i2c_t3.h>
#include <MIDI.h>
#include <ResponsiveAnalogRead.h>

#include "config.h"
#include "TxHelper.h"

// wrap code to be executed only under DEBUG conditions in D()
#ifdef DEBUG
#define D(x) x
#else
#define D(x)
#endif

MIDI_CREATE_DEFAULT_INSTANCE();

// midi write helpers
uint16_t current;
uint8_t high7bits, low7bits;
bool send14bitUSB, send14bitTRS;
uint32_t lastMidiActivityAt;
int midiDirty = 0;
const uint32_t midiFlashDuration = 50;
int ledPin = 13;

// the storage of the values; current is in the main loop; last value is for midi output
uint16_t volatile currentValue[channelCount];
uint8_t lastMidiValue[channelCount];
uint8_t lastLowMidiValue[channelCount];

// variables to hold configuration
int usbChannels[channelCount];
int trsChannels[channelCount];
int usbCCs[channelCount];
int trsCCs[channelCount];
uint16_t usbCCModes;
uint16_t trsCCModes;
int legacyPorts[channelCount]; // for V125 only
int flip;
int ledOn;
int ledFlash;
int i2cMaster;
int midiThru;

const int adcResolutionBits = 13; // 13 bit ADC resolution on Teensy 3.2
int faderMin;
int faderMax;

bool shouldSendForcedControlUpdate = false;
uint32_t sendForcedControlAt;

// variables for i2c master mode
// memory of the last unshifted value
uint16_t lastValue[channelCount];

// the i2c message buffer we are sending
uint8_t messageBuffer[4];

// temporary values
uint16_t valueTemp;
uint8_t device = 0;
uint8_t port = 0;

// master i2c specific stuff
const int ansibleI2Caddress = 0x20;
const int er301I2Caddress = 0x31;
const int txoI2Caddress = 0x60;
bool er301Present = false;
bool ansiblePresent = false;
bool txoPresent = false;


// the thing that smartly smooths the input
ResponsiveAnalogRead *analog[channelCount];

// mux config
CD74HC4067 mux(8, 7, 6, 5);
const int muxMapping[16] = {0, 1, 2, 3, 4, 5, 6, 7, 15, 14, 13, 12, 11, 10, 9, 8};

// MIDI timers
IntervalTimer midiWriteTimer;
IntervalTimer midiReadTimer;
int midiInterval = 1000; // 1ms
bool shouldDoMidiRead = false;
bool shouldDoMidiWrite = false;
bool forceMidiWrite = false;

// helper values for i2c reading and future expansion
int activeInput = 0;
int activeMode = 0;

/*
 * The function that sets up the application
 */
void setup()
{

  D(Serial.println("16n Firmware Debug Mode"));

  checkDefaultSettings();

  loadSettingsFromEEPROM();
  i2cMaster = EEPROM.read(3) == 1;

  if(i2cMaster) {
    delay(BOOTDELAY);
  }

  usbMIDI.setHandleSystemExclusive(processIncomingSysex);
  usbMIDI.setHandleRealTimeSystem(midiClock);

  if(midiThru){
    usbMIDI.setHandleNoteOff(midiNoteOff);
    usbMIDI.setHandleNoteOn(midiNoteOn);
    usbMIDI.setHandleAfterTouchPoly(midiAfterTouchPoly);
    usbMIDI.setHandleControlChange(midiControlChange);
    usbMIDI.setHandleProgramChange(midiProgramChange);
    usbMIDI.setHandleAfterTouch(midiAfterTouch);
    usbMIDI.setHandleTimeCodeQuarterFrame(midiTimeCodeQuarterFrame);
    usbMIDI.setHandleSongPosition(midiSongPosition);
    usbMIDI.setHandleSongSelect(midiSongSelect);
    usbMIDI.setHandleTuneRequest(midiTuneRequest);
  }


  #ifdef V125
  // analog ports on the Teensy for the 1.25 board.
  if(flip) {
    int portsToAssign[] = {A15, A14, A13, A12, A11, A10, A9, A8, A7, A6, A5, A4, A3, A2, A1, A0};
    for(int i=0; i < channelCount; i++) {
      legacyPorts[i] = portsToAssign[i];
    }
  } else {
    int portsToAssign[] = {A0, A1, A2, A3, A4, A5, A6, A7, A8, A9, A10, A11, A12, A13, A14, A15};
    for(int i=0; i < channelCount; i++) {
      legacyPorts[i] = portsToAssign[i];
    }
  }
  #endif

// initialize the TX Helper
#ifdef V125
  TxHelper::UseWire1(true);
#else
  TxHelper::UseWire1(false);
#endif
  TxHelper::SetPorts(16);
  TxHelper::SetModes(4);

  // set read resolution to teensy's 13 usable bits
  analogReadResolution(adcResolutionBits);

  // initialize the value storage
  for (int i = 0; i < channelCount; i++)
  {
    // analog[i] = new ResponsiveAnalogRead(0, false);

    analog[i] = new ResponsiveAnalogRead(0, true, .0001);
    analog[i]->setAnalogResolution(1 << adcResolutionBits);
    
    // ResponsiveAnalogRead is designed for 10-bit ADCs
    // meanining its threshold defaults to 4. Let's bump that for 
    // our 13-bit adc by setting it to 4 << (13-10)
    analog[i]->setActivityThreshold(32);

    currentValue[i] = 0;
    lastMidiValue[i] = 0;
    lastLowMidiValue[i] = 0;

    if(i2cMaster) {
      lastValue[i] = 0;
    }
  }

// i2c using the default I2C pins on a Teensy 3.2
if(i2cMaster) {

  D(Serial.println("Enabling i2c in MASTER mode"));

#ifdef V125
  Wire1.begin(I2C_MASTER, I2C_ADDRESS, I2C_PINS_29_30, I2C_PULLUP_EXT, 400000);
  Wire1.setDefaultTimeout(10000); // 10ms

  D(Serial.println ("Scanning I2C bus"));
  
  Wire1.begin();
  
  for (byte i = 8; i < 120; i++)
  {
    Wire1.beginTransmission (i);
    if (Wire1.endTransmission () == 0)
      {
        if(i == ansibleI2Caddress) {
          ansiblePresent = true;
          D(Serial.println ("Found ansible"));
        }

        if(i == txoI2Caddress) {
          txoPresent = true;
          D(Serial.println ("Found TXO"));
        }

        if(i == er301I2Caddress) {
          er301Present = true;
          D(Serial.println ("Found ER301"));
        }
      delay (1);  // maybe unneeded?
      } // end of good response
  } // end of for loop

  D(Serial.println ("I2C scan complete."));

#else
  Wire.begin(I2C_MASTER, I2C_ADDRESS, I2C_PINS_18_19, I2C_PULLUP_EXT, 400000);
  Wire.setDefaultTimeout(10000); // 10ms

  D(Serial.println ("Scanning I2C bus"));
  
  Wire.begin();
  
  for (byte i = 8; i < 120; i++)
  {
    Wire.beginTransmission (i);
    if (Wire.endTransmission () == 0)
      {
        if(i == ansibleI2Caddress) {
          ansiblePresent = true;
          D(Serial.println ("Found ansible"));
        }

        if(i == txoI2Caddress) {
          txoPresent = true;
          D(Serial.println ("Found TXO"));
        }

        if(i == er301I2Caddress) {
          er301Present = true;
          D(Serial.println ("Found ER301"));
        }
      delay (1);  // maybe unneeded?
      } // end of good response
  } // end of for loop

  Serial.println ("I2C scan complete.");

#endif

} else {
  // non-master mode

  D(Serial.println("Enabling i2c enabled in SLAVE mode"));

#ifdef V125
  Wire1.begin(I2C_SLAVE, I2C_ADDRESS, I2C_PINS_29_30, I2C_PULLUP_EXT, 400000);
  Wire1.onReceive(i2cWrite);
  Wire1.onRequest(i2cReadRequest);
#else
  Wire.begin(I2C_SLAVE, I2C_ADDRESS, I2C_PINS_18_19, I2C_PULLUP_EXT, 400000);
  Wire.onReceive(i2cWrite);
  Wire.onRequest(i2cReadRequest);
#endif

}

  // turn on the MIDI party
  MIDI.begin();
  midiWriteTimer.begin(writeMidi, midiInterval);
  midiReadTimer.begin(readMidi, midiInterval);

  pinMode(ledPin, OUTPUT);

  if(ledOn) {
    digitalWrite(ledPin, HIGH);
  }
}

/*
 * The main read loop that goes through all of the sliders
 */
void loop()
{
  // this whole chunk makes the LED flicker on MIDI activity - 
  // and inverts that flicker if the power light is on.
  if (ledFlash) {
    if (millis() > (lastMidiActivityAt + midiFlashDuration)) {
      if(ledOn) {
        digitalWrite(ledPin, HIGH);
      } else {
        digitalWrite(ledPin, LOW);
      }
      midiDirty = 0;
    } else {
      if(ledOn) {
        digitalWrite(ledPin, LOW);
      } else {
        digitalWrite(ledPin, HIGH);
      }
    }
  } else {
    if(ledOn) {
      digitalWrite(ledPin, HIGH);
    } else {
      digitalWrite(ledPin, LOW);
    }
  }

  if(shouldSendForcedControlUpdate && (millis() > sendForcedControlAt)) {
    // it's now time to send a forced control update, so...

    // disable this
    shouldSendForcedControlUpdate = false;

    // this will force a write the next time the midiWrite callback fires.
    forceMidiWrite = true;
  }

  // read loop using the i counter
  for (int i = 0; i < channelCount; i++)
  {
    int temp;
#ifdef V125
    temp = analogRead(legacyPorts[i]); // mux goes into A0
#else
    // set mux to appropriate channel
    if(flip) {
      mux.channel(muxMapping[channelCount - i - 1]);
    } else {
      mux.channel(muxMapping[i]);
    }
    // wait for the mux channel to change
    delayMicroseconds(10);

    // read the value
    temp = analogRead(0); // mux goes into A0
#endif

    // put the value into the smoother
    analog[i]->update(temp);

    if(analog[i]->hasChanged()) {
      // read from the smoother, constrain (to account for tolerances), and map it
      temp = analog[i]->getValue();

      temp = constrain(temp, faderMin, faderMax);

      temp = map(temp, faderMin, faderMax, 0, 16383);

      if(flip) {
        temp = 16383-temp;
      }

      // map and update the value
      currentValue[i] = temp;
    }
  }

  if (shouldDoMidiRead)
  {
    doMidiRead();
    noInterrupts();
    shouldDoMidiRead = false;
    interrupts();
  }

  if (shouldDoMidiWrite)
  {
    doMidiWrite();
    noInterrupts();
    shouldDoMidiWrite = false;
    interrupts();
  }
}

/*
 * Tiny function called via interrupt
 * (it's important to catch inbound MIDI messages even if we do nothing with
 * them.)
 */
void readMidi()
{
  shouldDoMidiRead = true;
}

/*
 * Function called when shouldDoMidiRead flag is HIGH
 */

void doMidiRead()
{
  MIDI.read();
  usbMIDI.read();
}

/*
 * Tiny function called via interrupt
 */
void writeMidi()
{
  shouldDoMidiWrite = true;
}

/*
 * The function that writes changes in slider positions out the midi ports
 * Called when shouldDoMidiWrite flag is HIGH
 */
void doMidiWrite()
{
  // "q" is a legacy holdover
  for (int q = 0; q < channelCount; q++)
  {
    current = currentValue[q];
    high7bits = (current >> 7) & 0x7F;
    low7bits = current & 0x7F;
    send14bitUSB = usbCCs[q] < 96 && ((usbCCModes >> q) & 1) == 1;
    send14bitTRS = trsCCs[q] < 96 && ((trsCCModes >> q) & 1) == 1;

    // if there was a change in the midi value
    if ((high7bits != lastMidiValue[q]) ||
        ((low7bits != lastLowMidiValue[q]) && (send14bitUSB || send14bitTRS)) ||
        forceMidiWrite)
    {
      if(ledFlash && !midiDirty) {
        lastMidiActivityAt = millis();
        midiDirty = 1;
      }
      // send the message over USB and physical MIDI
      usbMIDI.sendControlChange(usbCCs[q], high7bits, usbChannels[q]);
      if (send14bitUSB) {
        usbMIDI.sendControlChange(usbCCs[q] + 32, low7bits, usbChannels[q]);
      }
      MIDI.sendControlChange(trsCCs[q], high7bits, trsChannels[q]);
      if (send14bitTRS) {
        MIDI.sendControlChange(trsCCs[q] + 32, low7bits, trsChannels[q]);
      }

      // store the shifted value for future comparison
      lastMidiValue[q] = high7bits;
      lastLowMidiValue[q] = low7bits;

      D(Serial.printf("MIDI[%d]: %d\n", q, high7bits));
    }

    if(i2cMaster) {

      // we send out to all three supported i2c slave devices
      // keeps the firmware simple :)

      if (current != lastValue[q])
      {
        D(Serial.printf("i2c Master[%d]: %d\n", q, current));

        // for 4 output devices
        port = q % 4;
        device = q / 4;

        // TXo
        if(txoPresent) {
          sendi2c(txoI2Caddress, device, 0x11, port, current);
        }

        // ER-301
        if(er301Present) {
          sendi2c(er301I2Caddress, 0, 0x11, q, current);
        }

        // ANSIBLE
        if(ansiblePresent) {
          sendi2c(0x20, device << 1, 0x06, port, current);
        }

        lastValue[q] = current;
      }
    }
  }
  forceMidiWrite = false;
}

/*
 * Sends an i2c command out to a slave when running in master mode
 */
void sendi2c(uint8_t model, uint8_t deviceIndex, uint8_t cmd, uint8_t devicePort, int value)
{

  valueTemp = (uint16_t)value;
  messageBuffer[2] = valueTemp >> 8;
  messageBuffer[3] = valueTemp & 0xff;

#ifdef V125
  Wire1.beginTransmission(model + deviceIndex);
  messageBuffer[0] = cmd;
  messageBuffer[1] = (uint8_t)devicePort;
  Wire1.write(messageBuffer, 4);
  Wire1.endTransmission();
#else
  Wire.beginTransmission(model + deviceIndex);
  messageBuffer[0] = cmd;
  messageBuffer[1] = (uint8_t)devicePort;
  Wire.write(messageBuffer, 4);
  Wire.endTransmission();
#endif
}

/*
 * The function that responds to a command from i2c.
 * In the first version, this simply sets the port to be read from.
 */
void i2cWrite(size_t len)
{

  D(Serial.printf("i2c Write (%d)\n", len));

  // parse the response
  TxResponse response = TxHelper::Parse(len);

  // true command our setting of the input for a read?
  if (len == 1)
  {

    // use a helper to decode the command
    TxIO io = TxHelper::DecodeIO(response.Command);

    D(Serial.printf("Port: %d; Mode: %d [%d]\n", io.Port, io.Mode, response.Command));

    // this is the single byte that sets the active input
    activeInput = io.Port;
    activeMode = io.Mode;
  }
  else
  {
    // act on the command
    actOnCommand(response.Command, response.Output, response.Value);
  }
}

/*
 * The function that responds to read requests over i2c.
 * This uses the port from the write request to determine which slider to send.
 */
void i2cReadRequest()
{

  D(Serial.print("i2c Read\n"));

  // get and cast the value
  uint16_t shiftReady = 0;
  switch (activeMode)
  {
  case 1:
    shiftReady = (uint16_t)currentValue[activeInput];
    break;
  case 2:
    shiftReady = (uint16_t)currentValue[activeInput];
    break;
  default:
    shiftReady = (uint16_t)currentValue[activeInput];
    break;
  }

  D(Serial.printf("delivering: %d; value: %d [%d]\n", activeInput, currentValue[activeInput], shiftReady));

// send the puppy as a pair of bytes
#ifdef V125
  Wire1.write(shiftReady >> 8);
  Wire1.write(shiftReady & 255);
#else
  Wire.write(shiftReady >> 8);
  Wire.write(shiftReady & 255);
#endif
}

/*
 * Future function if we add more i2c capabilities beyond reading values.
 */
void actOnCommand(byte cmd, byte out, int value) {}

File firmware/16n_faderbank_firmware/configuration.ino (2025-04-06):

/*
 * 16n Faderbank EEPROM-based configuration
 * (c) 2020 by Tom Armitage
 * MIT License
 */

const int defaultUSBCCs[] = {32, 33, 34, 35, 36, 37, 38, 39, 40, 41, 42, 43, 44, 45, 46, 47};
const int defaultTRSCCs[] = {32, 33, 34, 35, 36, 37, 38, 39, 40, 41, 42, 43, 44, 45, 46, 47};

const int defaultUSBChannels[] = {1, 1, 1, 1, 1, 1, 1, 1, 1, 1, 1, 1, 1, 1, 1, 1};
const int defaultTRSChannels[] = {1, 1, 1, 1, 1, 1, 1, 1, 1, 1, 1, 1, 1, 1, 1, 1};

void checkDefaultSettings() {
  // if byte1 of EEPROM is FF for whatever reason, let's assume the machine needs initializing
  int firstByte = EEPROM.read(0x00);

  if(firstByte > 0x01) {
    D(Serial.println("First Byte is > 0x01, probably needs initialising"));
    initializeFactorySettings();
  } else {
    D(Serial.print("First Byte is set to: "));
    D(printHex(firstByte));
    D(Serial.println());
    byte buffer[80];
    readEEPROMArray(0, buffer, EEPROM_DATA_SIZE);
    D(Serial.println("Config found:"));
    D(printHexArray(buffer, EEPROM_DATA_SIZE));
  }
}

 void initializeFactorySettings() {
  // set default config flags (LED ON, LED DATA, ROTATE, etc)
  // fadermin/max are based on "works for me" for twra2. Your mileage may vary.
  EEPROM.write(0,1);  // LED ON
  EEPROM.write(1,1);  // LED DATA
  EEPROM.write(2,0);  // ROTATE
  EEPROM.write(3,0);  // I2C follower by default
  EEPROM.write(4,15); // fadermin LSB
  EEPROM.write(5,0);  // fadermin MSB
  EEPROM.write(6,71); // fadermax LSB
  EEPROM.write(7,63); // fadermax MSB
  EEPROM.write(8,0);  // Soft midi thru

  for(int i = 9; i < 16; i ++) {
    EEPROM.write(i,0);  // blank remaining config slots.
  }

  // set default USB channels
  for(int i = 0; i < channelCount; i++) {
    int baseAddress = 16;
    int writeAddress = baseAddress + i;
    EEPROM.write(writeAddress, defaultUSBChannels[i]);
  }

  // set default TRS channels
  for(int i = 0; i < channelCount; i++) {
    int baseAddress = 32;
    int writeAddress = baseAddress + i;
    EEPROM.write(writeAddress, defaultTRSChannels[i]);
  }

  // set default USB channel ccs
  for(int i = 0; i < channelCount; i++) {
    int baseAddress = 48;
    int writeAddress = baseAddress + i;
    EEPROM.write(writeAddress, defaultUSBCCs[i]);
  }

  // set default TRS channel ccs
  for(int i = 0; i < channelCount; i++) {
    int baseAddress = 64;
    int writeAddress = baseAddress + i;
    EEPROM.write(writeAddress, defaultTRSCCs[i]);
  }

  // set default CC modes
  for(int i = 0; i < 6; i++) {
    int baseAddress = 80;
    int writeAddress = baseAddress + i;
    EEPROM.write(writeAddress, 0x00);
  }

  // serial dump that config.
  byte buffer[EEPROM_DATA_SIZE];
  readEEPROMArray(0,buffer,EEPROM_DATA_SIZE);
  D(Serial.println("Config Instantiated."));
  D(printHexArray(buffer, EEPROM_DATA_SIZE));
}

void loadSettingsFromEEPROM() {
  // load usb channels
  for(int i = 0; i < channelCount; i++) {
    int baseAddress = 16;
    int readAddress = baseAddress + i;
    usbChannels[i] = EEPROM.read(readAddress);
  }

  D(Serial.println("USB Channels loaded:"));
  D(printIntArray(usbChannels,channelCount));

  // load TRS channels
  for(int i = 0; i < channelCount; i++) {
    int baseAddress = 32;
    int readAddress = baseAddress + i;
    trsChannels[i] = EEPROM.read(readAddress);
  }

  D(Serial.println("TRS Channels loaded:"));
  D(printIntArray(trsChannels,channelCount));

  // load USB ccs
  for(int i = 0; i < channelCount; i++) {
    int baseAddress = 48;
    int readAddress = baseAddress + i;
    usbCCs[i] = EEPROM.read(readAddress);
  }

  D(Serial.println("USB CCs loaded:"));
  D(printIntArray(usbCCs,channelCount));


  // load TRS ccs
  for(int i = 0; i < channelCount; i++) {
    int baseAddress = 64;
    int readAddress = baseAddress + i;
    trsCCs[i] = EEPROM.read(readAddress);
  }

  D(Serial.println("TRS CCs loaded:"));
  D(printIntArray(trsCCs,channelCount));

  // load USB CC mode flags
  usbCCModes = (EEPROM.read(80) & 0x7F) | ((EEPROM.read(81) & 0x7F) << 7) | ((EEPROM.read(82) & 0x03) << 14);

  D(Serial.println("USB CC modes loaded:"));
  D(printHex(usbCCModes >> 8));
  D(printHex(usbCCModes & 0xFF));
  D(Serial.println());

  // load TRS CC mode flags
  trsCCModes = (EEPROM.read(83) & 0x7F) | ((EEPROM.read(84) & 0x7F) << 7) | ((EEPROM.read(85) & 0x03) << 14);

  D(Serial.println("TRS CC modes loaded:"));
  D(printHex(trsCCModes >> 8));
  D(printHex(trsCCModes & 0xFF));
  D(Serial.println());


  // load other config
  ledOn = EEPROM.read(0);
  ledFlash = EEPROM.read(1);
  flip = EEPROM.read(2);
  midiThru = EEPROM.read(8);

  // i2cMaster only read at startup

  int faderminLSB = EEPROM.read(4);
  int faderminMSB = EEPROM.read(5);

  D(Serial.print ("Setting fadermin to "));
  D(Serial.println((faderminMSB << 7) + faderminLSB));
  faderMin = (faderminMSB << 7) + faderminLSB;

  int fadermaxLSB = EEPROM.read(6);
  int fadermaxMSB = EEPROM.read(7);
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

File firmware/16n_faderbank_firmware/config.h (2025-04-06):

/*
 * 16n Faderbank Firmware Configuration
 * (c) 2017,2018,2020 by Brian Crabtree, Sean Hellfritsch, Tom Armitage, and Brendon Cassidy
 * MIT License
 */


/*
 * firmware metadata
 */

int MAJOR_VERSION = 0x02;
int MINOR_VERSION = 0x02;
int POINT_VERSION = 0x00;

/*
 * device metadata
 */

#if defined(__MKL26Z64__) || defined(__MK20DX128__) || defined(_LC_DEBUG)
const int DEVICE_ID = 0x03; // 16nLC, do not change, needed by editor
#else
const int DEVICE_ID = 0x02; // 16n, do not change, needed by editor
#endif

// restricts output to only channel 1 for development purposes
// #define DEV 1

// activates printing of debug messages
// #define DEBUG 1

// enables legacy compatibility with non-multiplexer boards
// #define V125

// define startup delay in milliseconds for i2c Leader devices
// this gives follower devices time to boot up.
#define BOOTDELAY 10000

// I2C Address for Faderbank. 0x34 unless you ABSOLUTELY know what you are doing.
#define I2C_ADDRESS 0x34

#ifdef DEV

const int channelCount = 1;
const int ports[] = {A0};

#else

const int channelCount = 16;

#endif

// size of eeprom config
#define EEPROM_DATA_SIZE 86

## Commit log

2017-08-23 Initial commit.
    [16n-midijack.brd, 16n-midijack.sch]
2017-08-23 Adding legend to rear.
    [16n-midijack.brd, 16n-midijack.sch]
2017-11-03 SPI and MIDI breakouts.
    [16n-midijack.brd, 16n-midijack.sch]
2017-11-12 Various changes:
    - through hole componentry
    - up-to-date silking
    - protection diodes on II lines
    [16n-midijack.brd, 16n-midijack.sch]
2017-11-14 What I sent to Sean.
    [16n-midijack.brd, 16n-midijack.sch]
2017-11-15 Everything on the board.
    Now needs routing. Oh boy.
    [16n-midijack.brd, 16n-midijack.sch]
2017-11-15 Fixing up some layout.
    [16n-midijack.brd]
2017-11-15 Boom. Routed.
    [16n-midijack.brd, 16n-midijack.sch]
2017-11-17 New layout with horizontal jacks.
    [16n-midijack.brd, 16n-midijack.sch]
2017-11-18 Tidy silking and credits.
    [16n-midijack.brd]
2017-11-18 Helps if you tidy the impedence resistor silk too.
    [16n-midijack.brd]
2017-11-18 MIDI has to go to serial TX.
    [16n-midijack.brd, 16n-midijack.sch]
2017-11-18 First pass at firmware.
    [16n-midijack.brd]
2017-11-18 Dropping the word 'faderbank'.
    [16n-midijack.brd]
2017-11-23 Correcting outputs.
    [16n-midijack.brd, 16n-midijack.sch]
2017-11-23 Remove legacy trace names.
    [16n-midijack.brd, 16n-midijack.sch]
2017-11-23 Fix gate positions.
    [16n-midijack.brd, 16n-midijack.sch]
2017-11-23 WIP: rerouting.
    [16n-midijack.brd]
2017-11-23 Completed reroute. Blimey.
    [16n-midijack.brd]
2017-11-23 Remove ropey silking.
    [16n-midijack.brd]
2017-11-23 Add version number.
    [16n-midijack.brd]
2017-11-28 MIDI positive voltage should be 3V3 for Teensy 3.x. Fixed that.
    [16n-midijack.brd, 16n-midijack.sch]
2017-12-11 Make impedence jacks 1K.
    [16n-midijack.brd, 16n-midijack.sch]
2017-12-12 Move resistor so it won't interefere with standoff.
    [16n-midijack.brd]
2017-12-12 Add 2x8 header for I2C; add fiducials.
    [16n-midijack.brd, 16n-midijack.sch]
2017-12-17 Some minor tweaks.
    [16n-midijack.brd]
2017-12-18 Tweaks to layout, including moving jacks.
    [16n-midijack.brd]
2017-12-20 Move II to TRS; label II and MIDI jacks.
    [16n-midijack.brd, 16n-midijack.sch]
2017-12-30 1.2, sent for fab.
    [16n-midijack.brd]
2018-01-06 Text fixes.
    [16n-midijack.brd]
2018-02-07 Very minor routing tidying.
    [16n-midijack.brd]
2018-02-07 Calling things by their name.
    [16n.brd, 16n.sch]
2018-02-07 Panel stuff.
    [16n-final-grid-sized-panel.dxf, 16n-final-panel-min-sized.dxf]
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2018-02-08 fixed compatibility with final board (fader ordering and CV range) and added master mode capability
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2018-02-20 Rename MIDI device to '16n'.
    Note that for a Mac to detect this change you'll need to disconnect the 16n,
    go to "Audio/MIDI preferences", find the "Teensy MIDI" device and click 'remove'.
    Then, next time you connect 16n, it'll appear in your MIDI devices as '16n'.
2018-02-21 V1.21: three support holes in the middle of the board. Drills 2.5.
    [16n.brd]
2018-03-16 Fixing top right, adding radii.
    [16n.brd]
2018-03-16 Moved teensy 25mil north.
    [16n.brd]
2018-03-16 Space around M2.5 holes.
    [16n.brd]
2018-07-07 1.25 panel files.
    [16n-125-bottom.dxf, 16n-125-top.dxf, 16n-final-grid-sized-panel.dxf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]
2018-07-07 Eagle 9.1.0 version BRD: added CC licence/logo.
    [16n.brd]
2018-07-09 1.26 - tidying and CC logo.
    [16n.brd, 16n.sch]
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2018-07-17 Move electronics.
    [16n.brd, 16n.sch]
2018-07-17 Add 1.26 Gerber files.
    [16n.nonplated.drills.xln, 16n.plated.drills.xln]
2018-07-29 CSV BOM.
    [bom-csv.csv]
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2018-09-07 1.3 board.
    [16n_13.brd, 16n_13.sch]
2018-09-07 Given Teensy 3.2 AREF is 3.3V... let's strip out the inner pins.
    [16n_13.brd, 16n_13.sch]
2018-09-07 Tidying and eyeballing layout.
    [16n_13.brd, 16n_13.sch]
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2018-09-07 Remove old gerbers.
    [16n.nonplated.drills.xln, 16n.plated.drills.xln]
2018-09-07 Tidying some silking ugliness.
    [16n_13.brd]
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2018-09-10 This variable is no longer used.
    [config.h]
2018-09-10 New panel designs.
    [16n-125-top.dxf, 16n-131-bottom.dxf, 16n-131-top.dxf]
2018-09-10 Tidying silking, amongst other things.
    [16n_13.brd, 16n_13.sch, bom.csv]
2018-09-13 Goddamnit spell Brendon's name right.
    [16n_13.brd]
2018-09-14 Restore these labels, remove unnecessary via.
    [16n_13.brd]
2018-09-30 Updted BOM.
    [bom-csv.csv, bom.csv]
2018-09-30 1.31 board: updated component designators.
    [16n_13.brd, 16n_13.sch]
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2018-09-30 Updated gerbers.
    [16n_13.nonplated.drills.xln, 16n_13.plated.drills.xln]
2018-09-30 1.26 gets its own files. 1.31 is now the main version.
    [16n.brd, 16n.sch, 16n_13.brd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]
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2018-10-15 Move to EAGLE 9.2 style layout.
    [16n.brd, 16n.sch]
2019-01-02 Tweaking electronics README.
    [bom.csv]
2019-01-03 Specify 10k slide pots in bom.csv (this was already the case on Octopart).
    [bom.csv]
2019-01-03 Move legacy hardware to legacy directory.
    [16n_v126.brd, 16n_v126.sch]
2019-01-03 Fixing link to correct Octopart BOM.
2019-01-10 Fix a couple of typo's
2019-01-15 Fix I2C address of faderbank in slave mode, as per #12.
2019-01-15 Add frames and document versions to schematics, as per #4.
    [16n.sch]
2019-01-15 Add version as global value to BRD file, too.
    [16n.brd]
2019-01-18 Correct part in CSV BOM, fixing #6.
    [bom.csv]
2019-01-18 Fixing #10: correct size holes in panels.
    In the meantime, I've also used LibreCAD to fettle the panels a tad and
    get them the right way up, etc.
    [16n-131-bottom.dxf, 16n-131-top.dxf]
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2019-01-20 Flag to flip faders top/bottom.
    [config.h]
2019-01-20 Actually working approach to flipping values for both MIDI and I2C.
2019-01-20 Rename panels for 1.32
    [16n-132-bottom.dxf, 16n-132-top.dxf]
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2019-02-01 Update Ansible I2C address.
    No effect for end users, but because Ansible uses 7-bit addresses, these
    are equivalent. However, making the string the same as the one in `ii.h`
    for consistency across ecosystem.
2019-02-21 Change suggested compilation settings for firmware.
    Use MIDI, not Serial+MIDI, in Arduino IDE in order to avoid problems
    with hardware devices.
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2019-08-14 Revert to correct panel DXFs.
    Owing to an error, incorrect DXFs were added to v1.32 and v1.33: whilst
    they had the correct drill sizes for holes, they had the wrong panel
    size. Some people have manufactured incorrect panels, as such. (The
    panels still fit, they're just a bit large.)
    This reverts to the correct, "approved" 16n panel size.
    [16n-132-bottom.dxf, 16n-132-top.dxf, 16n-134-bottom.dxf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]
2019-09-30 Potential fix for I2C Master issues.
    i2c hangs upon endTransmission if no i2c devices are connected.
    This is correct behaviour, or, at least, known behaviour.
    This fix currently has ugly syntax and could be refactored, but should
    behave correctly:
    - when in MASTER mode, on bootup, scan the i2c bus
    - mark 301/txo/ansible as present if they are
    - in future, only send messages to known devices. don't send messages to
    addresses that aren't connected.
    Requires test from somebody with such devices, but it works as a MIDI
    device with no i2c connected.
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2019-10-04 Fix bug with DEV mode.
    [config.h]
2020-02-21 Tidying up FLIP and LED options.
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2020-04-09 Handle sysex short messages as appropriate.
    [sysex.ino]
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2020-05-08 Clarity around panel files + lasercutting files.
    It wasn't clear that the mechanical drawing PDFs are _only_ for
    reference. Some people also have had issues making panels from the DXFs.
    So:
    * added PDFs for cutting courtesy of Matt Kennedy
    * added clarity around what the various panel files are _for_.
2020-12-29 Add functionality to reset EEPROM remotely (#42)
    * Implemetation of MIDI Pass Thru
    Successsfully tested on Teensy3.2 and Teensy LC builds
    * Soft MIDI Thru now set by byte 8 of config RAM.
    * Add Sysex message to force factory reset.
    As per #41, it should be possible to remotely reset the EEPROM to
    factory defaults. This adds a sysex message that should do that.
    * Blank all config slots on factory reset.
    [config.h, configuration.ino, midiThru.ino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]
2021-04-05 Bugfix: once factory settings are reset, they need to be loaded, otherwise the old settings are floating around.
    [sysex.ino]
2021-04-05 Delay bootup if 16n is in i2c master/leader mode.
    This solves some issues users with the device hardwired - and, for
    instance, users of compatible devices, like "Sweet Sixteen", have had,
    where the leader would boot before their connected follower devices
    (like an ER-301) were ready.
    [config.h]
2023-04-03 Rename directory and main FW filename.
    Arduino 2.0 IDE no longer likes filenames beginning with an underscore.
    Never mind. This rename keeps things happy.
    [16n_faderbank_firmware.ino, TxHelper.cpp, config.h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]
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

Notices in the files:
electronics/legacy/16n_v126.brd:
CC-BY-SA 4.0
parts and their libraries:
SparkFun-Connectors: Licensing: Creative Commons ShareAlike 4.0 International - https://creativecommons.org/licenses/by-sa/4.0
